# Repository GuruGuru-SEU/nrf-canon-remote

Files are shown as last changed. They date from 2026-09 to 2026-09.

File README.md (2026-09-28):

# nRF52832 Canon remote — mechanical study v0.12

打开 **[在线 3D 预览](https://guruguru-seu.github.io/nrf-canon-remote/preview.html)**，可直接分享这个链接。

也可下载 `output/preview.html` 后用浏览器离线打开，详见 [机械设计说明](output/设计说明.md)。

机身为 **78 × 43 × 17.35 mm**：保留四向圆环、中心两段键和下方三个圆键，删除长条键及底部五个矩形键。中心开关采用 **K2-1831SL-A4SW-01**，其余七个开关采用 TS-1101-C-W。外壳、PCB 外形、固定孔、USB-C 板舌与开孔配套重建；软包电池候选为 EEMB LP402535 / 320 mAh。

USB-C 选用淘宝自购的 **HX TYPE-C 6P QTWT（6Pin 全贴）**，对应立创 C18357553，按当前 PCB 改为底面安装。USB-C、TS-1101-C-W 和 RGB 的预览使用嘉立创下载模型，原始文件与来源见 [器件模型记录](reference/component-models/README.md)。中心两段开关采用界面显示角度 180°，仍按厂家图纸建模；nRF52832 与电池为外形包络。U600 底部声学端口增加 Ø1.2 mm 外壳声孔与 Ø2.2 mm 内侧 relief。

v0.10 修正 USB-C 底面安装的翻转：焊脚朝 PCB，母座主体朝背盖，焊盘同步翻转。恢复参考外壳 USB 端两侧的上盖楔形卡扣和下盖凹槽，托筋避开固定焊耳。中心开关的两个定位孔也随 180° 方向旋转；模型碰撞检查不再豁免 USB / 外壳或开关 / PCB 穿插。预览新增“USB-C 端部配合”和“端部上盖卡扣”。

v0.12 按 2026-09-23 Chrome 最终 PCB 将上方 Ø2.3 孔移至 (14,28)，上下盖螺柱与沉孔同步。最初按 EDA 叠层临时建模为 1.0 mm；2026-09-24 用户确认实际板厚为 1.6 mm，已保持 PCB 上表面不变、将底面和底装 USB-C 下移 0.60 mm，并同步调整托台。USB 模型使用实际焊盘核验原点偏移。

2026-09-28 更新 **[openEMS 天线初步计算报告](https://guruguru-seu.github.io/nrf-canon-remote/rf/antenna-20260923.html)**：使用 9 月 24 日最终 Gerber 的全部两面铜和钻孔、1.6 mm 板厚，以及立创公开 FR-4 参数；提供六组裸板 / 装壳 / 材料敏感性 / 网格细化结果及原始端口数据。此前 PCB 快照计算和匹配候选已被本轮取代。现 PCB 使用印制天线，下面 v0.1 电气草案中的陶瓷天线与部分元件值已不是最终 PCB 版本。RF 结果仍有材料、网格和端口近似，不能直接作为量产匹配 BOM；[复算方法](scripts/rf/README.md)与数据一并提供。

2026-09-28 新增 **[三种候选板材分别计算的报告](https://guruguru-seu.github.io/nrf-canon-remote/rf/materials-20260928.html)**：NP-140F、HY-8101，以及按官方树脂含量表拆分的 NY2140 RC55/RC70。报告同时说明 L 型与 π 型匹配网络，并给出含电感的 C-L-C 候选、材料共用扫描和八组 openEMS 证据。

新增 **[文字原理图 v0.1](output/electrical/原理图-v0.1.md)**：包含 nRF52832 最小系统、9 路按键信号、RGB 驱动、USB／电池供电与充电、4Pin SWD、陶瓷天线、库存 BOM 和布局注释。依据见 [电气参考资料](reference/electrical/README.md)。目前为待转绘和验证的电路草案，不含 EDA 原理图工程、PCB 铜层布局或固件；新增电路器件尚未回填到 3D 模型。

用于分享审阅的 HTML 页面：**[7 页原理图图纸](https://guruguru-seu.github.io/nrf-canon-remote/electrical/schematic-drawing-v0.1.html)**、**[原理图说明](https://guruguru-seu.github.io/nrf-canon-remote/electrical/schematic-v0.1.html)**、**[完整 BOM](https://guruguru-seu.github.io/nrf-canon-remote/electrical/bom-v0.1.html)**。图纸用 Schemdraw 绘制，支持切页、缩放、位号定位和 SVG 下载，每页附连接与 layout 注释；网站首页不增加文档入口。

图纸逐器件标注 `JLC C…` 物料编号，可在嘉立创EDA直接搜索；60 个元件对应 27 种立创物料。RGB 已改为共阳接 VDD、三个 GPIO 经各自限流电阻低有效直驱。未核实或待选型的器件、DNP 和 PCB 自带焊盘分别注明。物料编号与完整 BOM 一致；2026-09-19 新核实的四项供应商链接见 BOM，采购状态仍为待采购。

2026-09-20 按已有开发板用值更新晶振负载：HF、LF 每侧各一颗 12 pF（C210～C213，C45359894），后续电容顺延为 C214～C218；旧／新位号对照见文字原理图 3.2 节。

按键采用 GPIO 直连触点到地，开启内部上拉并由固件去抖；删除 R300～R308、C300～C308 共 18 个元件，半按与全按各自保留独立输入。

3D 预览为机械模型。参考键帽保留形状并平移、修改顶柱；下盖恢复参考工程的梯形截面（43 mm 收至背面 35 mm）；PCB 左上、右上角设 R5 四分之一圆凹口，下盖增加配合定位凸台和托台；采用右上、下左右三点固定。RGB 与导光结构整体下移 5 mm。原始 140 mm 参考模型保留在预览的“原型对照”中。

## 输出

- `output/electrical/原理图-v0.1.md`：可转绘的文字原理图、引脚分配、BOM 和 layout 原则。
- `output/electrical/BOM-v0.1.md`：按电路部分拆分的完整 BOM，包含已有／待采购状态和用途。
- `output/electrical/*.html`：可独立浏览及发布到 Pages 的原理图与 BOM 页面。
- `output/electrical/schematic-assets/*.svg`：7 页矢量电路图，覆盖全部默认装配物料、DNP、测试点和 MCU 48 脚 + EP。
- `output/electrical/schematic-manifest.json`、`schematic-checks.json`：绘图连接数据与检查记录；不是 EDA 网表，也不代表通过 EDA ERC。
- `output/preview.html`：模型及 Three.js 全部内嵌，双击离线打开。支持装配、爆炸、剖切、透明、梯形端面、PCB 板形、角部配合、USB 特写、中心键半按/全按及 STL 下载。
- `output/models/remote_assembly.3mf`：含电子件占位的完整装配。
- `output/models/printable_parts.3mf`：上下盖、五个键帽、导光件，共八件。
- `output/models/*.stl`：各部件，保持装配坐标，单位 mm。
- `output/models/pcb_outline.dxf`、`pcb_outline.svg`：板框、三个安装孔及中心开关的两个定位孔。
- `output/review/`：几何/浏览器检查、截图及尺寸依据。

## 重建与检查

```sh
uv sync --locked
npm ci
uv run python scripts/build_models.py
uv run python scripts/check_exports.py
npm run build
npm run check:preview
```

Python 3.14 与 `.venv` 由 uv 管理，依赖定义于 `pyproject.toml`，精确版本锁定于 `uv.lock`。新增 Python 依赖使用 `uv add 包名`；`requirements.txt` 为兼容 pip 的导出文件，可用 `uv export --no-hashes --no-dev -o requirements.txt` 更新。

更新电气 Markdown 后，运行 `npm run build:docs` 重新导出两份 HTML。构建使用本机 Google Chrome 将 Mermaid 框图渲染为 SVG；最终 HTML 无外部运行时依赖，不需要重新构建机械模型。

图形原理图的连接数据位于 `scripts/electrical_circuit.py`，绘图代码位于 `scripts/draw_schematics.py`。更新电路时同时更新文字原理图、BOM 和连接数据，然后运行：

```sh
npm run build:schematics
npm run check:schematics
```

物料编号及无编号原因维护在 `electrical_circuit.py` 的 `JLC_GROUPS` / `NO_JLC` 中。构建检查每页的器件标注覆盖，校验脚本比对 BOM 编号并确认 SVG 中实际显示了各条标注。

检查覆盖 75 个 BOM 位号/焊盘位置、65 件默认装配物料、41 件电阻/电容/电感的数值、49 个 MCU 引脚、9 路按键直连、3 路 RGB 直驱，以及图中全部 215 个端子的实际连线。浏览器检查包含文字重叠/裁切、移动页面、切页、缩放和位号定位；这些属于文档与绘图一致性检查，不能替代电气 ERC 和样机测试。网页可离线浏览，SVG 下载依赖同目录的 `schematic-assets/`。

布局及开关尺寸统一定义于 `scripts/layout.json`。建模脚本使用 trimesh / manifold，打印件出现非封闭、非连通实体或已检查部件穿透时会终止导出；库模型的检查方式与例外在器件模型记录中列明。浏览器检查使用已安装的 Google Chrome，包含离线加载、视图、两段键运动、STL 导出和移动屏幕排版。

尚未实物验证按键手感、打印公差、螺纹强度、导光混色及 USB 线缆包胶空间；详细尺寸与假设见设计说明。

## GitHub Pages 发布

推送 `main` 分支中的预览、模型或电气 HTML 更新后，GitHub Actions 自动发布 GitHub Pages。网站根目录和 `/preview.html` 均可打开预览，`/models/` 下提供模型下载，`/electrical/` 下提供文档直链。部署过程发布已生成的文件。

修改布局或建模代码后，先执行上面的重建和检查命令，再提交并推送 `scripts/` 与 `output/` 的更新。也可在 Actions 页面手动运行发布工作流。

原始采购订单含个人收货信息，不上传到公开仓库；所用物料见 [公开物料信息](reference/jlc-orders/README.md)。本地虚拟环境、依赖缓存和历史试验文件同样不提交。

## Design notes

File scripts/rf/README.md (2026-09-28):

# Gerber 驱动的 openEMS 计算（2026-09-24）

当前几何来自用户提供的 `Gerber_nRF52832遥控器_2026-09-24.zip`，SHA-256 为 `3fc97f87b7eec812915d751c0682821ee30cdcd28201358806b40dc6174ed5ac`。不再使用前一天封装拼接天线。几何包含全部两面铜、PTH/NPTH；飞针文件只用于识别 L220 焊盘位置。原始 ZIP 保留本地，提取的 JSON 足以复算。没有原始 ZIP 时跳过下方 `extract_gerber.py`，直接使用仓库中的 JSON 运行求解。

独立 uv 环境使用 Python 3.13：

```sh
uv venv --python 3.13 .tools/openems/.venv
uv pip install --python .tools/openems/.venv/bin/python pip setuptools setuptools-scm wheel cython numpy h5py matplotlib shapely scipy gerbonara==1.6.3
```

本机按 [openEMS 官方指南](https://docs.openems.de/en/latest/install/clone-build-install.html) 编译 openEMS 0.37.0 / CSXCAD 0.7.0，安装前缀 `.tools/openems`。系统依赖为 Homebrew 的 cmake、boost、hdf5、cgal、vtk；原生安装不提交 Git。构建扩展时将该 uv 环境加入 PATH，设置 VIRTUAL_ENV，执行 `update_openEMS.sh <安装前缀> --disable-GUI --njobs=8 --python --python-venv-mode=disable`。

```sh
set -o pipefail
mkdir -p tmp
.tools/openems/.venv/bin/python scripts/rf/extract_gerber.py
.tools/openems/.venv/bin/python scripts/rf/simulate.py --name gerber-bare --mesh .2 2>&1 | tee tmp/rf-gerber-bare.log
.tools/openems/.venv/bin/python scripts/rf/simulate.py --name gerber-fine --mesh .15 2>&1 | tee tmp/rf-gerber-fine.log
.tools/openems/.venv/bin/python scripts/rf/simulate.py --name gerber-finer --mesh .1 2>&1 | tee tmp/rf-gerber-finer.log
.tools/openems/.venv/bin/python scripts/rf/simulate.py --name gerber-low-loss --mesh .15 --loss .013 2>&1 | tee tmp/rf-gerber-low-loss.log
.tools/openems/.venv/bin/python scripts/rf/simulate.py --name gerber-dk43 --mesh .15 --eps 4.3 2>&1 | tee tmp/rf-gerber-dk43.log
.tools/openems/.venv/bin/python scripts/rf/simulate.py --name gerber-housed --mesh .15 --shell-eps 2.8 2>&1 | tee tmp/rf-gerber-housed.log
.tools/openems/.venv/bin/python scripts/rf/analyze_gerber.py
node scripts/rf/build_report.mjs
```

三份板材的独立计算与汇总：

```sh
.tools/openems/.venv/bin/python scripts/rf/run_materials.py --threads 4
.tools/openems/.venv/bin/python scripts/rf/analyze_materials.py
python3 scripts/rf/build_material_report.py
node scripts/rf/build_material_report.mjs
```

`analyze_materials.py` 会校验八组实际求解、扫描 L/π 理想匹配网络，并生成
`output/rf/materials-matching.json`、对比图和求解证据 ZIP。NY2140 按制造商
R/C 55% 与 70% 两个官方表格工况分别计算；三份输入 PDF 和参数清单在
`reference/rf/materials/` 与 `reference/rf/materials-20260928.json`。

运行名唯一对应几何和参数，不要对仍在运行的目录再次执行。`--post` 只后处理已有时域数据，必须使用相同参数。

默认板厚 1.6 mm，Dk=4.5，Df=0.02。材料来源及频率限制见 `reference/rf/materials-20260924.json`。Dk=4.5 是立创双层板公开典型值；Df=0.02 是其 1 MHz 通用值，不能声称为此订单 2.4 GHz 实测值。低损耗对照 Df=0.013 来自建滔 KB-6160 厚芯板 2 GHz 参数，未断言订单使用此料号。

50 Ω 集总端口位于 **L220 天线侧焊盘**，跨板厚连接对面地铜。电路元件不装，不包含射频芯片阻抗。C216/L220/C217 数值未嵌入 EM 模型。匹配综合同时扫描并联支路在负载端 / 输入端的两种理想 L 网络，仅适用于这个端口。不能直接套用到现板位号。

模型保留 Gerber 中细小铜间隙及独立焊盘的嵌套关系，但 FDTD 网格可能遗漏小图元，日志会记录警告。过孔按孔半径 + 25 µm 的实心导体近似，铜采用 PEC 片，阻焊开窗已解析但介质本身未纳入。省略元件负载、铜损、USB 金属、螺钉、人体；装壳组仅假设上下盖 εr=2.8、tanδ=0.01，并加入机械布局对应的浮置电池导体包络。

`gerber-solver-evidence.zip` 保存本轮所有求解日志、端口时域数据和参数。历史 `*-16` 及无后缀输出保留对照；它们不是最新 Gerber 结果。旧快照提取脚本 / 旧匹配脚本仅供历史复现，默认主流程以上述命令为准。

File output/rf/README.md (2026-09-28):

# 最终 Gerber · 1.6 mm PCB 天线计算

**2026-09-28 整理完成。** 已按用户提供的 `Gerber_nRF52832遥控器_2026-09-24.zip` 重建电磁几何，完成六组 openEMS 仿真。本文替代此前基于 PCB 快照的报告；旧的 `42.1 + j47.4 Ω` 裸板结果及其匹配候选不再作为当前版本的依据。

> 初步结论：当前模型的天线馈点偏感性，装壳和电池影响明显。计算可以提供调试起点，但尚不足以确定最终匹配 BOM。以下均为仿真结果，非样机实测。

## 简报

| 条件 | 2.441 GHz 输入阻抗 | BLE 频段最差未匹配 S11 |
|---|---:|---:|
| 裸板，最细 0.10 mm 射频 XY 网格 | **11.10 + j45.44 Ω** | **−1.74 dB** |
| 裸板，0.15 mm 网格（装壳组对照） | 11.72 + j48.07 Ω | −1.75 dB |
| 装壳 + 浮置电池包络，0.15 mm 网格 | **12.05 + j118.82 Ω** | **−0.56 dB** |

频段为 **2.402–2.480 GHz**，阻抗参考面位于 **L220 天线侧焊盘 `$1N324`**。正虚部表示感性。这里测的是该焊盘看向馈线与天线的输入阻抗，不是 nRF52832 ANT 引脚阻抗，也不是完整装配电路的输入阻抗。

有限取值的理想两元件匹配扫描得到：裸板可用**输入侧并联 1.8 pF + 串联 3.0 pF**作为计算候选，频段最差 S11 约 **−8.58 dB**；装壳假设下另行扫描的候选为**输入侧并联 1.5 pF + 串联 0.7 pF**，约 **−6.55 dB**。这两组在本次扫描中均未覆盖全频段 −10 dB 目标，不能据此宣称天线已经调好，也不代表所有网络都无法达到目标。

## 立创 FR-4 参数依据

- [立创官方 PCB 能力表](https://jlcpcb.com/capabilities/pcb-capabilities)给出的双层 FR-4 介电常数为 **Dk = 4.5**，此项没有标明频率。本轮采用它作为名义基准。
- [立创官方 FR-4 页面](https://jlcpcb.com/pcb-fabrication/fr4-pcb)给出典型 **Df ≈ 0.02（1 MHz）**。它不是本订单在 2.4 GHz 的已知实测值；本轮仅用作基准假设。
- [建滔 KB-6160 官方材料表](https://www.kblaminates.com/upload/ueditor/20220525/KB-6160-0831.pdf)中，59 mil / 7628×8 一行在 2 GHz 给出 Dk = 4.5、Df = 0.013，Dk 公差 ±0.2。本轮增加 **Df = 0.013** 和 **Dk = 4.3** 两组独立敏感性计算；这不表示已确认订单使用 KB-6160，也不是该订单的公差承诺。

板厚采用用户确认的 **1.6 mm**。Gerber 本身不包含板材牌号和介电参数。源网页查阅日期为 2026-09-24；[参数记录与来源校验值](https://github.com/GuruGuru-SEU/nrf-canon-remote/blob/main/reference/rf/materials-20260924.json)可供追溯。

## 实际建模内容

本次直接解析最终制造文件中的两面全部铜、板框、101 个 PTH 和 6 个 NPTH。`Drill_PTH_Through_Via.DRL` 的过孔已包含在总 PTH 文件内，没有重复建模。飞针数据用于识别 L220 馈点；Gerber 铜几何已核对天线馈点、IFA 短路端以及 L220 两焊盘的分离关系。

天线直接来自最终底层 Gerber，没有用旧封装拼接。天线顶部区域与前一版快照基本一致；但本次纳入全部网络铜、完整钻孔和新的材料参数，因此两版模型不等价，不能把全部阻抗差异归因于 Dk 的变化。

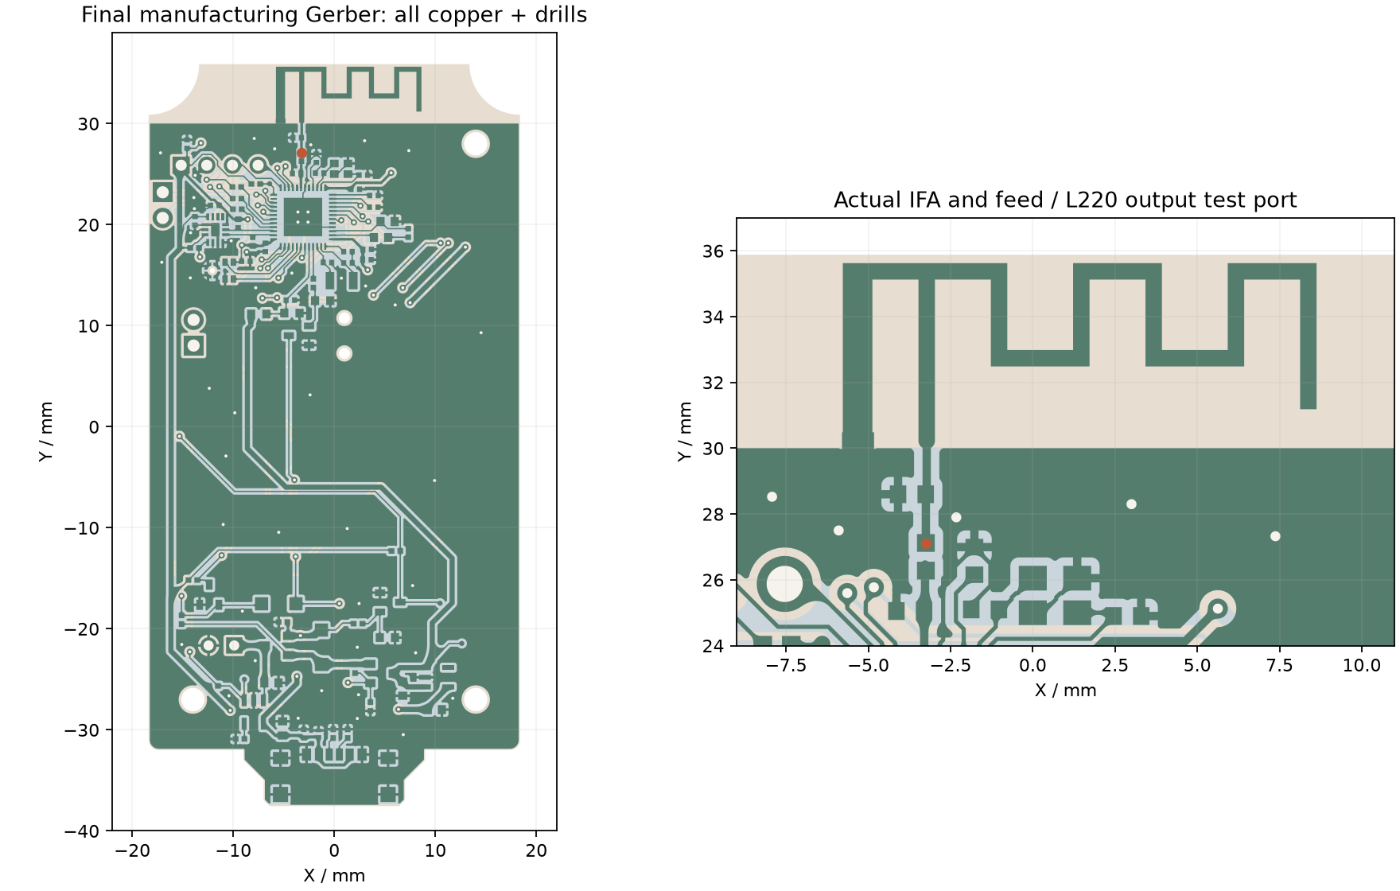
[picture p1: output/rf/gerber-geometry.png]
最终 Gerber 铜层、钻孔及 L220 馈点


图中底层铜为深绿、顶层铜为灰蓝，橙点为仿真端口。左图全板，右图放大天线区域。

- 铜采用 PEC 薄片；板厚换算为 **1.545 mm 铜面间距**，扣除名义铜厚及阻焊余量。这是近似叠层，不是板厂确认的实际叠层。
- PTH 采用孔半径 + 25 µm 的实心导体近似，不是空心孔壁模型。阻焊开窗已提取供核查，阻焊介质未纳入求解。
- 50 Ω 集总端口沿板厚连接底面 RF 焊盘与正对的顶面地铜，未做实际同轴探针和测试夹具去嵌。
- 器件不装配；C216、L220、C217 数值和芯片阻抗未嵌入模型。其他网络保留铜，但没有器件负载；这与完整 PCBA 有区别。
- 装壳组使用 v0.12 上下盖 STL，假设壳体 εr = 2.8、tanδ = 0.01，并加入机械布局对应的浮置导体电池包络。电池引线、USB 金属壳、按键、螺钉和人体均未包含。
- FR-4 损耗通过 2.45 GHz 处的等效电导率实现，在该频率对应所设 Df；没有模拟完整的材料频散。

## 六组结果与数值检查

| 计算组 | 射频 XY 网格 | Dk / Df | 2.441 GHz 阻抗 | 频段最差 S11 |
|---|---:|---:|---:|---:|
| 裸板基准 `gerber-bare` | 0.20 mm | 4.5 / 0.020 | 11.14 + j53.32 Ω | −1.52 dB |
| 裸板细化 `gerber-fine` | 0.15 mm | 4.5 / 0.020 | 11.72 + j48.07 Ω | −1.75 dB |
| 裸板再细化 `gerber-finer` | 0.10 mm | 4.5 / 0.020 | 11.10 + j45.44 Ω | −1.74 dB |
| 较低损耗 `gerber-low-loss` | 0.15 mm | 4.5 / 0.013 | 10.73 + j48.02 Ω | −1.61 dB |
| 较低介电常数 `gerber-dk43` | 0.15 mm | 4.3 / 0.020 | 12.05 + j41.64 Ω | −2.00 dB |
| 壳体与电池 `gerber-housed` | 0.15 mm | 4.5 / 0.020 | 12.05 + j118.82 Ω | −0.56 dB |

六组均达到 **−40 dB 时域能量停止阈值**。已经检查端口数据有限、实部为正，并核对阻抗换算 S11 与导出的 Touchstone 一致。这是基本数值检查，不等于与实物一致。

裸板射频区 XY 网格从 0.20 → 0.15 mm 时，中心频率阻抗变化 **10.68%**；0.15 → 0.10 mm 时仍变化 **5.77%**，频段内最大阻抗差 **3.28 Ω**。板厚方向保持 5 个单元，外围网格较粗，装壳组未继续细化。最细组还有 19 条未被网格使用的图元警告，涉及小铜片、空隙和部分孔柱。**因此不能声称严格网格收敛，也不应把上述小数位理解为实际精度。**

## 匹配候选怎么理解

下图仅表示在该参考面前接入理想网络后的电路关系，不是现有 PCB 的元件位号替换图：

```text
理想 50 Ω 输入 ──●──── Cs ──── 原始 Gerber 负载
                 │               ↑ L220 天线侧参考面
                 Cp
                 │
                GND
```

| 针对条件 | 输入侧并联 Cp | 串联 Cs | 匹配后频段最差 S11 |
|---|---:|---:|---:|
| 裸板，0.10 mm 网格 | 1.8 pF | 3.0 pF | −8.58 dB |
| 装壳假设，0.15 mm 网格 | 1.5 pF | 0.7 pF | −6.55 dB |

将同一组裸板候选用于 0.15 mm 裸板时，最差 S11 为 −7.34 dB；用于装壳组仅为 **−0.47 dB**。这说明当前误差和装配环境足以改变匹配值。0.15 mm 与 0.10 mm 两组裸板各自扫描得到的串联电容也分别为 2.7 pF 和 3.0 pF。

扫描同时考虑输入侧、负载侧并联的两种 L 网络，候选包含电容 0.2–10 pF、电感 0.5–22 nH 中的离散值及开路 / 短路；目标是降低 BLE 频段最差 S11。元件为理想集中参数，未计入 Q、ESR、SRF、焊盘和走线寄生。上述数值不能直接替换现有 L220 / C216 / C217，也不取代芯片端的 Nordic 参考网络。

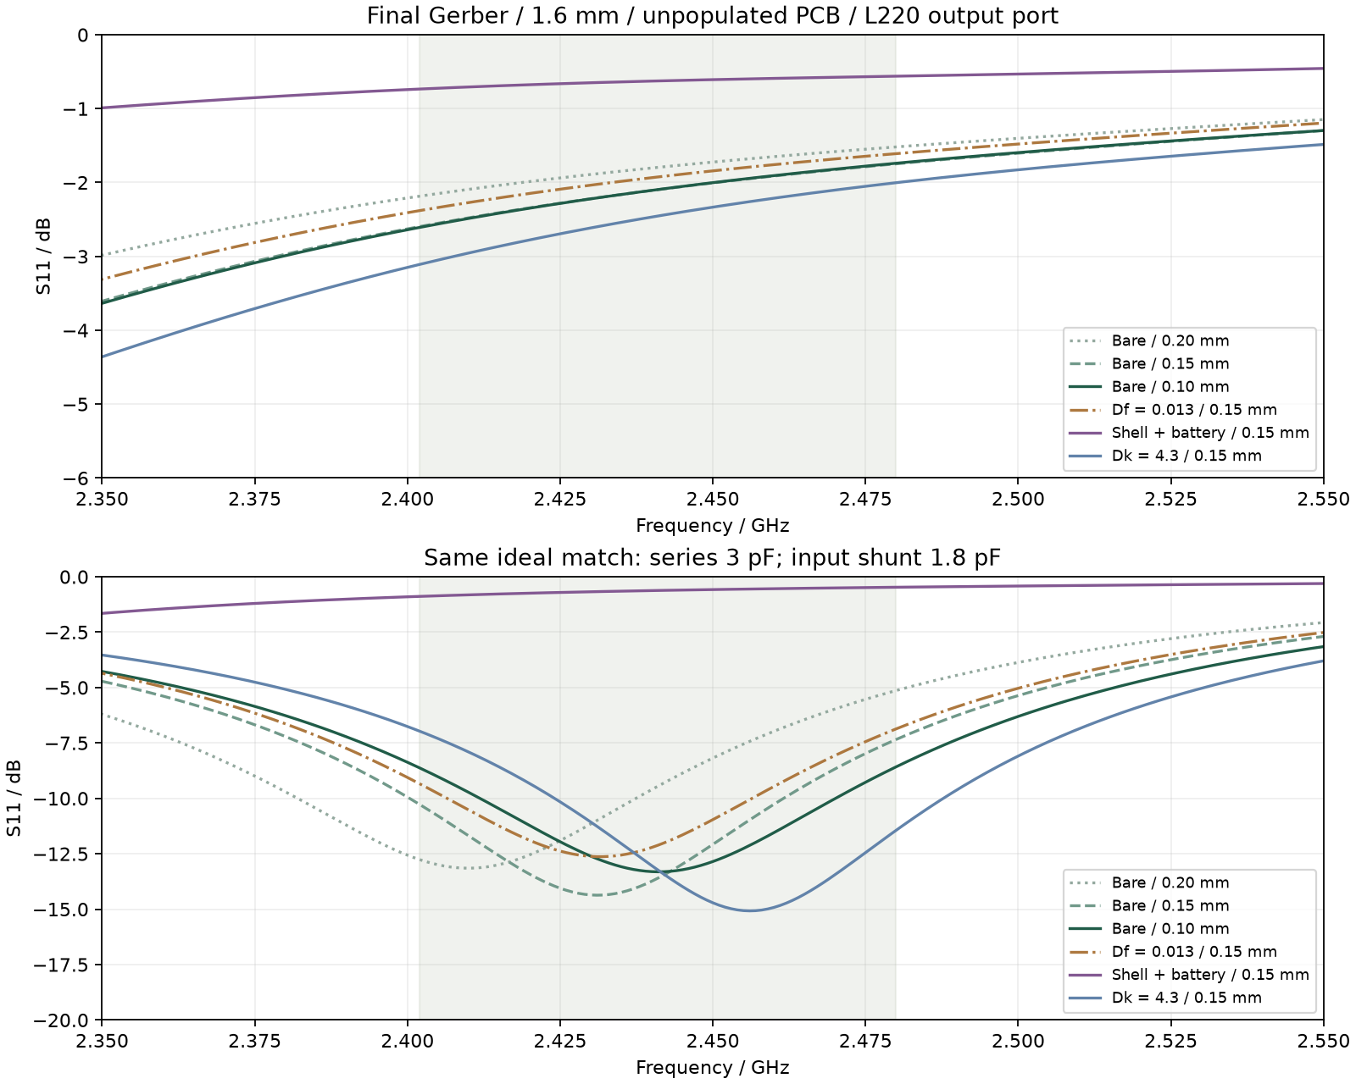
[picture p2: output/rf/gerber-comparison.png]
未匹配与同一裸板候选作用下的 S11 对比


上图为各条件原始 S11，下图统一使用裸板候选 Cp = 1.8 pF、Cs = 3.0 pF，绿色阴影表示 BLE 频段。下图没有对各曲线单独重新优化。

**建议下一步：** 保留天线端调试焊盘，先确认实际板材及叠层，再用最终电池与外壳装配样机，在一致的参考面通过 VNA 测量后选定元件。当前结果支持“需要调谐且装壳影响大”这一判断；本次没有计算辐射效率或遥控距离。

## 下载与复算

- [0.10 mm 裸板 S1P](gerber-finer.s1p) · [CSV](gerber-finer.csv) · [参数](gerber-finer.json)
- [0.15 mm 裸板 S1P](gerber-fine.s1p) · [CSV](gerber-fine.csv) · [参数](gerber-fine.json)
- [0.20 mm 裸板 S1P](gerber-bare.s1p) · [CSV](gerber-bare.csv) · [参数](gerber-bare.json)
- [装壳与电池 S1P](gerber-housed.s1p) · [CSV](gerber-housed.csv) · [参数](gerber-housed.json)
- [Df = 0.013 对照 S1P](gerber-low-loss.s1p) · [CSV](gerber-low-loss.csv) · [参数](gerber-low-loss.json)
- [Dk = 4.3 对照 S1P](gerber-dk43.s1p) · [CSV](gerber-dk43.csv) · [参数](gerber-dk43.json)
- [匹配扫描与数值检查](gerber-matching.json) · [Gerber 几何核查](gerber-audit.json)
- [六组求解日志、端口时域数据与参数 ZIP](gerber-solver-evidence.zip)
- [提取的制造几何](https://github.com/GuruGuru-SEU/nrf-canon-remote/blob/main/reference/rf/gerber-20260924.json) · [复算步骤与脚本](https://github.com/GuruGuru-SEU/nrf-canon-remote/tree/main/scripts/rf)
- [机械 3D 预览](../preview.html?rev=0.12) · [装配 3MF](../models/remote_assembly.3mf)

原始 ZIP 的 SHA-256：`3fc97f87b7eec812915d751c0682821ee30cdcd28201358806b40dc6174ed5ac`。源文件导出时间为 2026-09-24 14:07:48。本轮没有修改用户 PCB Layout。旧计算文件保留供历史比较，均不代表本次最终 Gerber 结果。

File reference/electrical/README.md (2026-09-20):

# 电气设计参考资料

核对日期：2026-09-17。本目录收录首次文字原理图使用的厂商资料，版权归各原作者。工程设计见 [原理图 v0.1](../../output/electrical/原理图-v0.1.md)。采购来源和设计选型不同：目录中有资料，不代表该器件已经采购。

## Nordic

| 资料 | 原始来源 | 本地文件／用途 |
| --- | --- | --- |
| nRF52832 QFAx Reference Layout v1.1 | [Nordic 官方 ZIP](https://nsscprodmedia.blob.core.windows.net/prod/software-and-other-downloads/reference-layouts/nrf52832qfaxreflayoutv11.zip) | [QFAA DC/DC 原理图](nrf52832_qfaa_dcdc_schematic.pdf)、[QFAA DC/DC PCB](nrf52832_qfaa_dcdc_pcb.pdf)，从官方压缩包提取，未改动 |
| Product Specification：引脚 | [Pin assignments](https://docs.nordicsemi.com/r/bundle/ps_nrf52832/page/pin.html) | QFN48 的脚号、VDD、VSS、DEC 与 GPIO |
| Product Specification：参考电路 | [Reference circuitry](https://docs.nordicsemi.com/r/bundle/ps_nrf52832/page/ref_circuitry.html) | 3.9 nH / 0.8 pF RF 网络、DC/DC 和去耦 BOM |
| Product Specification：时钟 | [CLOCK](https://docs.nordicsemi.com/r/bundle/ps_nrf52832/page/clock.html) | 晶体负载、引脚电容、ESR、精度要求 |
| Product Specification：ADC | [SAADC](https://docs.nordicsemi.com/r/bundle/ps_nrf52832/page/saadc.html) | 电池分压的采集时间与输入范围 |
| Product Specification：GPIO | [GPIO](https://docs.nordicsemi.com/r/bundle/ps_nrf52832/page/gpio.html) | RGB 直驱采用 H0S1；驱动电流、低电平压降与初始化配置 |
| Errata 138 | [Rev.3 anomaly 138](https://docs.nordicsemi.com/r/bundle/errata_nrf52832_rev3/page/err/nrf52832/rev3/latest/anomaly_832_138.html) | P0.25/P0.26 的参考电容处理 |
| PCB 指南 | [nRF52832 Specific PCB Guidelines](https://devzone.nordicsemi.com/guides/hardware-design-test-and-measuring/b/nrf5x/posts/nrf52832-specific-pcb-guidelines) | 补充解释 DEC2 的封装差异、C13/C14 和局部布局；该页面标为旧指南，结合当前规格及官方参考文件使用 |

## 库存器件资料

| 物料 | 文件 | 来源／核对内容 |
| --- | --- | --- |
| C52212029 / NH-B1515RGBA-GF | [PDF](NH-B1515RGBA-GF.pdf) | [国星厂商 PDF，立创托管](https://atta.szlcsc.com/upload/public/pdf/source/20251030/EECF4F56E4F8547E9265236F0C1AEE5B.pdf)；第 6 页引脚，2 共阳、1 红、3 蓝、4 绿 |
| C2925419 / KH-2012-HM1 | [PDF](KH-2012-HM1.pdf) | [金航标官网 PDF](https://www.kinghelm.net/upload/file/20240619/KH-2012-HM1.pdf)；第 2 页焊盘与净空，1 INPUT、2 NC；第 3 页示例板和匹配 |
| C49208527 / MSTP4054-42 | [PDF](MSTP4054-42.pdf) | [美森科厂商 PDF，立创托管](https://atta.szlcsc.com/upload/public/pdf/source/20250701/DF15CD7DF13D43087D35725B366D9DAB.pdf)；引脚、电流公式、充电终止条件 |
| C82942 / ME6211C33M5G-N | [PDF](ME6211.pdf) | [微盟 ME6211 系列 PDF，立创托管](https://atta.szlcsc.com/upload/public/pdf/source/20170918/C82942_1505727073070976520.pdf)；SOT23-5 的 C 系列引脚及 C33 电气参数；首页与 C33 表静态电流存在差异，按较高值预算 |
| C2891732 / SI2302 | [PDF](SI2302.pdf) | [永裕泰厂商 PDF，立创托管](https://atta.szlcsc.com/upload/public/pdf/source/20260225/4C26798752F14A6C8689DB8E1FD76F36.pdf)；N-MOS，1G/2S/3D，低压栅极驱动规格 |
| C54427949 / YE32MDBCD2X | [系列 PDF](YE32MDBCD2X.pdf) | [雅晶鑫系列 PDF，立创托管](https://atta.szlcsc.com/upload/public/pdf/source/20260323/688CCC4499BA77041AC465C19328DD85.pdf)；1/3 晶体、2/4 GND。完整料号的 32 MHz / 10 pF 见库存记录与[对应商品](https://item.szlcsc.com/57752896.html)，通用 PDF 未单独列出该订购后缀 |
| C18209174 / KFC3276812520T | [PDF](KFC3276812520T.pdf) | [凯越翔厂商 PDF，立创托管](https://datasheet.lcsc.com/datasheet/pdf/f310e2e4c21d4f7a5e8427f5db47ddd3.pdf?productCode=C18209174)；CL=12.5 pF、32.768 kHz、ESR 最大 70 kΩ |
| C411950 / SCL1608S100KSP，**不选用** | 系列数据来源 | [顺翔诺 SCL 系列 PDF，立创托管](https://datasheet.lcsc.com/lcsc/2304140030_Sunltech-Tech-SCL1608Q3R3KSP_C411948.pdf)；链接所属 SKU 是同系列其他感值，需读表内 **SCL1608S100KSP** 行；额定电流 3 mA，不能当作 Nordic 参考电路要求的 ≥50 mA 电感 |

USB-C 与普通轻触开关的库资料继续使用 [component-models](../component-models/README.md)。中心开关使用 [K2-1831SL-A4SW-01 厂商图纸](../../output/review/k2-1831sl-datasheet.pdf)，以图中的 a/b/c 触点标记核对封装。

## 本版新增选件依据

- [AO3401A，AOS 厂商规格](https://www.aosmd.com/pdfs/datasheet/AO3401A.pdf)（[本地 PDF](AO3401A.pdf)）：P-MOS 电池通路，不能以库存 SI2302 N-MOS 代替。
- [BAT54H，Nexperia 厂商规格](https://assets.nexperia.com/documents/data-sheet/BAT54H.pdf)：SOD123F 肖特基，用于 USB→VSYS；只通过系统电流。
- [MLZ1608M100WT000，TDK 厂商页面](https://product.tdk.com/en/search/inductor/inductor/smd/info?part_no=MLZ1608M100WT000)：10 µH、0603、电感变化额定电流 90 mA。

RF 的 3.9 nH 和 0.8 pF 按 Nordic QFN48 参考 BOM 新增采购，完整厂商料号尚未锁定；天线匹配预留元件待实板调试。没有把库存近似值标成已验证替代件。

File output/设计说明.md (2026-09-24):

# 遥控器机械改型 v0.12

本版机身 **78 × 43 × 17.35 mm**（不含按键突出），相比原始 140 mm 缩短 62 mm。保留四向圆环、中心键、下方三个圆键，共五个键帽、八个开关；三个长条键和底部五个矩形键全部删除。中心开关改为 **K2-1831SL-A4SW-01**，其余七个为 **TS-1101-C-W**。本版按 Chrome 中当前 PCB 的界面显示角度，将中心两段开关设为 **180°**。

打开 [preview.html](preview.html) 可离线预览。提供“中心两段键”特写、“中心剖切”及“松开 / 半按 / 全按”控制。动作表示几何行程；不表示已实现对焦、快门或 BR-E1 协议。

## 模型来源与边界

原始文件为 `reference/enclosure/shell_top.3mf`、`shell_bottom.3mf`、`buttons_blank.3mf`，板框参考 `reference/pcb/GerberFiles/profile.gbr`。

本版上下壳按参考的宽度、厚度、圆角和正面倒角风格重新建立，安装结构采用右上、下左右三组配套螺柱。不是直接沿用原壳全部内结构。圆环、中心、三个圆键保留原始键帽形状，只做刚性平移并增加相应顶柱；没有将圆形沿单轴压缩。原型对照展示未缩放的原始 140 mm 外壳、全部原始键帽及 Gerber 板框。

PCB 仅做机械外形、孔及 USB 焊盘配合展示，不包含原理图、铜层布线或完整封装设计。USB-C、七个 TS-1101-C-W 与 RGB 的预览使用嘉立创原始下载网格，来源、UUID、SHA-256、坐标转换及限制见 [器件模型记录](../reference/component-models/README.md)。当前 HX TYPE-C 6P QTWT 按 EasyEDA 中 J100 的底面安装状态翻到 PCB 下方，库模型使用底面镜像并保留其开口朝机身尾端的 XY 基准；焊脚面与十个 PCB 焊盘逐一检查。顶部外壳不切 USB 开口；下盖保留端口贯穿孔、11 × 5.1 mm 外侧浅让位及 12.4 mm 耳位让位。USB 端两侧恢复参考外壳的上盖楔形卡扣和下盖凹槽，扣槽名义间隙 0.15 mm、与 PCB 边缘间隙 0.25 mm。U600 为底部声孔麦克风，下盖新增 Ø1.2 mm 声孔与 Ø2.2 mm 内侧 relief。中心 K2-1831SL-A4SW-01 仍按厂家图纸建模；主控和电池为包络。STL/3MF 为网格实体，没有原生 CAD 特征树或 STEP 曲面。

## 统一坐标与布局

从正面看，X 向右，Y 向遥控器顶部，Z 向观察者。外壳正面 Z=0；全部尺寸单位 mm。

| 项目 | 当前尺寸 / 坐标 |
| --- | --- |
| 壳体 | X=±21.5；Y=±39；Z=-17.35 至 0 |
| 面板 / 侧壁 | 厚 1.20 / 1.70 |
| 分壳缝 | 上壁到 Z=-5.10，下壁到 -5.30，名义轴向间隙 0.20 |
| 圆环与中心键 | 中心 (0, 9) |
| 圆环四开关 | (0,18.69)、(-9.69,9)、(9.69,9)、(0,-0.69) |
| 三个圆键及开关 | (-11.43,-14)、(0,-14)、(11.43,-14) |
| LED / 导光孔 | (-11.43,29) |
| PCB | 总长 73.4287、宽 36.7574、厚 1.60；Y=-37.55 至 +35.8787 |
| PCB 高度 | 下表面 -9.05；上表面 -7.45 |
| 三个固定轴 | 右上 (14,28)；下左右 (-14,-27)、(14,-27) |
| 固定孔 | PCB Ø2.30；下壳通孔 Ø2.20 / 沉孔 Ø4.20；上壳导孔 Ø1.70 |
| 按键孔侧隙 | 由真实键帽截面向外偏移 0.20 |

固定方式按 M2 级螺钉尺寸预留，尚未选定螺钉、验证塑料螺纹或拉拔强度。下盖托起 PCB、上盖螺柱抵住 PCB 上表面；三轴完全对应。

## 顶角四分之一圆凹口与下盖配合

PCB 主体两侧为直边。左上、右上角以 (±18.3787,35.8787) 为圆心，各切除一个 **R5 的四分之一圆**，属于凹形让位。底角保留 R1。板框宽度 36.7574、板顶 Y=35.8787，包含 USB 板舌后的总长为 73.4287 mm。

参考工程下盖有与 PCB 圆弧让位配合的圆形凸台。本版将这种配合方式移至两个上角，重新设计定位台并与下盖侧壁、底板合为一体，参考截面见 [原工程板框与下盖](review/reference-pcb-retention.png)。

| 顶角配合 | 当前参数 |
| --- | --- |
| 凹口圆心 | (-18.3787,35.8787)、(18.3787,35.8787) |
| PCB 凹口 | R5.00，圆弧角度 90° |
| 下盖定位凸台 | R4.75，与凹口同心；名义径向间隙 0.25 |
| 导入斜面 | 从 PCB 顶面 Z=-7.45 到 -7.05，高 0.40、径向缩小 0.40 |
| 下方托台 | R5.60，伸到 PCB 下方；顶面 Z=-9.20，距 PCB 下表面 0.15 |
| 上下盖配合 | 定位凸台最高 -7.05，低于上盖配合唇底部 -6.50 |
| 螺丝固定 | 右上 (14,28)、下左右 (±14,-27)，PCB 孔 Ø2.30 |

凸台外侧裁到原有壳体包络内，保持梯形外形。角部凸台负责定位、托台预留支撑间隙；螺丝固定仍由三组贯穿 PCB 的安装柱承担。0.25 / 0.15 mm 是建模名义间隙，实际打印和 PCB 外形加工公差需样件核对。

RGB、上盖透光孔、导光柱及遮光筒保持 v0.7 的坐标 **(-11.43,29)**（相较 v0.6 下移 5 mm）。LED 位于有效板面内；导光件与两侧定位台、按键均已做干涉检查。

下盖继续采用参考工程的梯形截面：外侧从 Z=-11.35 开始斜收，到 Z=-17.35 时左右各内收 4.00，宽度由 43 变为 35 mm。内壁从 Z=-11.7367、X=±19.8 收到内底面 Z=-16.15、X=±16.8578，底板厚 1.20 mm。两下方沉孔到背面侧边的名义边距为 1.40 mm。

预览中的“PCB 板形”展示两个凹形顶角；“角部配合”展示 PCB、下盖与 LED。该视图下取消“PCB 与 USB 板舌”图层，可查看下盖定位凸台和托台。

## 中心两段式开关

依据韩荣官网提供的 **K2-1831SL-A4SW-□□** 图纸（尾号为序列号）建立 A4SW-01 机械模型。图纸保存在 [k2-1831sl-datasheet.pdf](review/k2-1831sl-datasheet.pdf)，可查看 [尺寸图](review/k2-1831sl-drawing.png)。未用相近的 SF 系列或 A4SA 型替代尺寸。

| 项目 | 厂家尺寸 / 当前适配 |
| --- | --- |
| 主体 | 6.20 × 6.50 × 2.00 |
| 最高点 | 距 PCB 上表面 3.80（主体 2.00 + 操作柱 1.80） |
| 操作柱 | Ø2.50 |
| 四端子 | 外侧总跨度 8.40；两排间距 4.50；端子宽 0.70 |
| 定位柱 | 两根 Ø1.00，伸入板内 0.80；相对开关中心 (-1,±1.75) |
| PCB 定位孔 | 两个 Ø1.10，绝对坐标 (1,7.25)、(1,10.75) |
| 第一段 / 第二段累计行程 | 0.30 / 0.55；第二段不是额外再下压 0.55 |
| 中心键顶柱 | Ø2.10；底端 Z=-3.50，比普通键顶柱缩短 1.30 |
| 静态间隙 | 开关顶面 -3.65 至键帽顶柱底端 -3.50：0.15 |
| 半按 / 全按键帽总位移 | 0.45 / 0.70，包含 0.15 空程 |

中心键源外观保持不变。开关壳体中预留操作柱运动腔，仅用于几何示意，不复刻内部弹片。预览中键帽与开关操作柱分别按总位移和实际开关行程移动。几何检查覆盖中心键 0–0.70 mm 内 15 个位置，检查上盖、圆环、PCB、开关壳体及运动操作柱的接触关系。

普通七个开关使用 C318938 原始库模型，整体包络约 8.007 × 3.70 × 2.498（含焊脚）；名义总高 2.50。普通键顶柱底面 -4.80，与下载模型最高点的间隙约 0.152。普通键按 0.15 空程 + 0.25 行程进行轴向下压检查。圆环实际倾斜、材料弹性、回弹和两段手感仍需打印试装；0.15 是名义值，不是已完成公差叠加后的保证值。

## USB-C、供电与导光

| 项目 | 当前尺寸 / 处理 |
| --- | --- |
| USB-C | 淘宝自购 HX TYPE-C 6P QTWT；对应立创 C18357553，6Pin 全贴 |
| 母座主体 | 图纸主体 8.94 × 6.80 × 3.16；库模型焊耳宽 11.44，图纸 11.80；库网格总高（含焊脚）3.26 |
| USB 前 / 后端 | Y=-39.20 / -32.40；母座口比壳体尾端名义平面伸出 0.20 |
| 端口中心 | X=0，Z=-10.73（距 PCB 下表面 1.68，底面安装） |
| 板舌 | 相对主板底边 Y=-32 向下延伸 5.55，到 -37.55；中央直段宽 14 |
| 贯穿开孔 | 9.60 × 3.90；宽向单侧 0.33、高向约 0.37 名义间隙（下盖） |
| 内侧板舌让位 | 焊耳让位宽 12.40；外侧浅让位 11.00 × 5.10；底面 USB 与下盖配合 |
| USB 库焊盘 | 六个端子 + 四个固定脚，全部为 SMT；距板边最小约 0.407 mm |
| 外侧浅让位 | 11.0 × 5.1，用于入口倒让；下盖两侧另有参考楔形扣槽 |
| 板舌托筋 | 两根宽 1.50，顶面 -9.20，距 PCB 下表面 0.15 |
| 电池候选 | EEMB LP402535，320 mAh；厂商外形 25.5 × 36 × 4.3 |
| 电池位置 | 中心 (0,0)，底面 -15.40、顶面 -11.10，位于 PCB 背面 |
| 电池空间 | 27 × 40 × 5.2 名义分配；四周限位不预压软包 |
| 主控 | nRF52832，6 × 6 × 0.85 QFN48 包络；PCB 背面中心 (0,21) |
| RGB | 订单 C52212029 / NH-B1515RGBA-GF；嘉立创源网格 1.6 × 1.5 × 1.02 |
| 导光孔 / 导光柱 | Ø3.50 / Ø3.20；可见顶面 Z=+0.15 |
| 导光肩 / 遮光筒 | 肩 Ø4.50；上壳一体遮光筒外径 Ø6.30 |
| 导光件底部 | Z=-5.98；距库模型 LED 顶面 0.45 |
| 麦克风声孔 | U600 中心 (-11.25,15.45)；下盖 Ø1.20，内侧 Ø2.20 relief |

电池是另购候选，需按实际保护板、引线和封边版本核对，未宣称复用原 BOM 的 1100 mAh 电池。RGB 按库模型总高 1.02 调整导光柱，较上一版缩短 0.32；高度及焊接偏差仍需实物核对。导光柱需独立采用透明材料，从内侧装入后在肩部固定。

USB 直接采用该物料关联的嘉立创 3D 模型，六个端子焊脚与四个外壳固定脚均为 SMT，不增加通孔。显示其库封装焊盘用于板边支撑核对，未设计铜层和电气网络。库网格焊耳总宽与 HX 图纸相差 0.36，已额外检查 11.80 mm 的较宽包络，未缩放预览网格。入口为充电用途规划；正式封装、插头包胶、焊接/打印偏差及受力仍需验证。

## 物料来源

| 用途 | 物料来源 | 本版数量 |
| --- | --- | --- |
| 中心开关 | `reference/jlc-orders/another-one.txt`：K2-1831SL-A4SW-01 | 1 |
| 其他开关 | SO26050844135，第 17 项；C318938 / TS-1101-C-W，订单 10 个 | 7 |
| USB-C | 淘宝单独购买 HX TYPE-C 6P QTWT；对应 C18357553，不在立创订单中 | 1 |
| RGB | SO2607130348，第 6 项；C52212029 | 1 |
| 主控 | 所给订单中未找到 nRF52832，按指定型号占位 | 1 |
| 电池 | EEMB LP402535 候选，另购 | 1 |

订单数量不代表当前实际库存。充电芯片、稳压器、天线、其他阻容尚未做电气适配；新增麦克风条目不属于本轮机械改型范围。

## 导出与检查结果

- [完整装配 3MF](models/remote_assembly.3mf)：含电子器件占位，不应整件打印。
- [打印件 3MF](models/printable_parts.3mf)：上盖、下盖、五个键帽、导光件，共八件。
- [中心两段键 STL](models/key_center.stl)、[上盖](models/shell_top.stl)、[下盖](models/shell_bottom.stl)、[PCB](models/pcb.stl)。
- [PCB DXF](models/pcb_outline.dxf) / [SVG](models/pcb_outline.svg)：一个外轮廓、三个固定孔、两个开关定位孔。

STL/3MF 保留统一装配坐标，单位 mm；切片前分别选择方向并落到热床。`models` 已移除不再使用的矩形键与长条键导出，避免误用旧版。

[几何报告](review/geometry-checks.json) 检查 29 个部件的碰撞实体，对 59 组包络重叠候选做布尔求交，目前无外部装配穿透。USB/普通开关先将各自库模型的内部实体合并，RGB 的非封闭库网格以保守外包络检查。USB 焊盘和电池胶带属于表面展示，不参与装配碰撞；USB 十个焊盘另逐一做了金属接触检查。另检查 11.80 mm 焊耳包络、两个 90° 凹口及同心凸台间隙、孔位、顶柱连接、中心键 15 个按压位置，以及参考梯形宽度。所有打印件均为封闭、正体积、单体连通网格。

[导出检查](review/export-checks.json) 重新读取全部 11 个 STL 和两份 3MF，确认实体有效、包络对应、3MF 单位为 mm，板框包含六个闭合轮廓。USB-C 的 STL 包含整只母座；RGB 在 3MF 中使用封闭外包络，原始细节网格只用于 HTML 预览。

[浏览器报告](review/browser-checks.json) 验证器件来源与原始三角面数量、六个端子及四个固定脚、PCB 装配视图、离线加载、无脚本错误、梯形端面、顶角凹口、下盖配合、LED 位置及三点固定坐标、正面/背面/特写、爆炸、透明、图层、剖切、未缩放原型对照、两段运动、STL 下载及移动屏幕横向排版。截图保存在 `review`。

本版完成机械几何评审，尚未实物试装。没有进行结构强度、疲劳、打印收缩、LED 混色、按键材料变形或电气/RF 验证。

## 尺寸资料

- [韩荣 K2-1831SL 官方系列页](http://www.krhro.com/Product-Details/142.html)；[官方 A4SW 尺寸 PDF](http://omo-oss-file110.thefastfile.com/portal-saas/pg2026081913505947704/cms/file/k2-1831sl%283%29.pdf)。
- [星坤 TS-1101-C-W 厂家尺寸图](https://datasheet.lcsc.com/datasheet/pdf/588e2cdf2775df050133e65c68ada42d.pdf?productCode=C318938)。
- [韩下 HX TYPE-C 6P QTWT 厂家尺寸图](../reference/component-models/C18357553.pdf)。
- [EEMB LP402535 厂商页](https://eemb.store/products/lp402535)。
- [Nordic nRF52832 封装信息](https://docs.nordicsemi.com/r/bundle/ps_nrf52832/page/ordering_info.html)。

### 2026-09-23 最终 PCB 同步

上方孔由 (0,28) 移至 (14,28)，孔径 2.30 mm。数据来自 Chrome 当前文档的 API 只读导出，三个孔的图元 ID 和坐标保存在 `scripts/layout.json` 的 `pcb_source`。用户于 2026-09-24 确认实际下单板厚 1.6 mm。PCB 上表面保持 -7.45，底面下移到 -9.05，底装 USB 开孔中心同步下移 0.60 mm。

USB 库模型原点相对于封装原点有 Y=-1.38194 mm 的偏移，已显式校正，并逐一与最终 PCB 的十个实际焊盘中心比对，误差小于 0.004 mm。

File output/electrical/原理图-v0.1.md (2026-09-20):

# nRF52832 Canon 遥控器：文字原理图 v0.1

更新日期：2026-09-20。用于转绘原理图和开始 PCB 规划；遥控器本板尚未完成 EDA ERC、PCB layout、射频调试或样机验证。

[查看 7 页图形原理图](schematic-drawing-v0.1.html)：含元件符号、引脚编号、数值和 layout 注释，与本文同步更新。BAT54H 厂商脚号为 2=阳极、1=阴极。

2026-09-19：图纸已逐器件补充 `JLC C…` 物料编号，未确定编号的器件、DNP 位置与自带焊盘也分别标注。编号及采购状态见 [完整 BOM](BOM-v0.1.md)。

2026-09-20：按用户已有开发板的用值反馈，HF、LF 晶振两侧均采用各一颗 12 pF 对地电容，合计四颗；后续 200 段电容位号顺延，具体对应见 3.2 节。

2026-09-20 按键简化：删除 R300～R308、C300～C308 共 18 个元件，9 路触点直接连接 GPIO，使用内部上拉与固件去抖；连接统一使用 `KEY_*` 网络名。

本版对应目前的机械方案：四向圆环、中心 K2-1831SL-A4SW-01 两段键、下排三个圆键、NH-B1515RGBA-GF RGB、HX TYPE-C 6P QTWT 和单节软包锂电池。7 个普通开关 + 1 个两段开关，共 **9 路按键信号**。主控选 **nRF52832-QFAA，QFN48，6 × 6 mm**，不使用 WLCSP 的引脚表。

建议转绘为五页：① USB／充电／电源；② MCU／时钟；③ 按键／RGB；④ RF／天线；⑤ SWD／测试点。相同网络名直接相连。下文所有 `GND` 属于同一电气网络，`NC` 是不连接，`DNP` 是保留焊盘但首版不装。

## 1. 总体结构与电源网络

```mermaid
flowchart LR
  USB[USB-C 6Pin / 5 V] --> CHG[MSTP4054-42 / 100 mA]
  CHG --> BAT[1S 带保护软包电池]
  USB --> D[肖特基二极管]
  D --> SYS[VSYS]
  BAT --> PMOS[P-MOS 电池通路]
  PMOS --> SYS
  USB -. 插线时关闭电池通路 .-> PMOS
  SYS --> LDO[ME6211 / 3.3 V]
  LDO --> VDD[VDD / R104 后]
  VDD --> MCU[nRF52832-QFAA]
  VDD --> RGB[共阳 RGB / 每色独立限流]
  MCU -. GPIO 低有效 / PWM .-> RGB
  KEY[7 个单段 + 1 个两段开关] --> MCU
  SWD[1 VDD / 2 GND / 3 IO / 4 CLK] <--> MCU
  MCU --> RF[Nordic RF 参考网络]
  RF --> MATCH[天线匹配预留]
  MATCH --> ANT[KH-2012-HM1]
```

| 网络 | 含义／允许连接 |
| --- | --- |
| `VBUS_5V` | USB 输入；连接充电器、USB 电源通路和 USB 检测 MOS 的栅极电路 |
| `VBAT` | **电池保护板输出 P+**；满电约 4.2 V，不能直连 MCU VDD |
| `VSYS` | 切换后的系统电源；电池时接近 VBAT，USB 时约为 VBUS 减去二极管压降 |
| `VREG_3V3` | ME6211 输出，经过 R104 到 VDD |
| `VDD` | MCU／GPIO 与 RGB 共阳电源，正常约 3.3 V；低电量时可能低于 3.3 V |
| `DEC1` / `DEC3` / `DEC4` | MCU 内部电源节点；仅连接指定无源件，不能给外部器件供电 |

USB 口用于供电和充电。该 6Pin 接口没有 USB 数据线；nRF52832 也没有原生 USB 控制器。

## 2. USB-C、充电与供电切换

### 2.1 J100：HX TYPE-C 6P QTWT

采用自购的 6Pin 全贴母座，对应 C18357553。[厂家图纸](../../reference/component-models/C18357553.pdf)与库封装一起复核，不使用之前 16Pin 型号的焊盘编号。

| J100 引脚／焊盘 | 连接 |
| --- | --- |
| A9、B9 | `VBUS_5V`，两脚都接 |
| A12、B12 | `GND`，两脚都接 |
| A5 / CC1 | `USB_CC1` |
| B5 / CC2 | `USB_CC2` |
| 金属壳焊脚（现有库编号 17～20） | `GND` |

```text
R100  5.1k  1% 0402 : USB_CC1 — GND          [C25905]
R101  5.1k  1% 0402 : USB_CC2 — GND          [C25905]
C100  100nF 16V 0402: VBUS_5V — GND         [C60474]
D101  PESDNC2FD5VB  : VBUS_5V — GND         [C5356109，双向 ESD]
D102  PESDNC2FD5VB  : USB_CC1 — GND         [C5356109，双向 ESD]
D103  PESDNC2FD5VB  : USB_CC2 — GND         [C5356109，双向 ESD]
```

CC1、CC2 **各自一个** 5.1 kΩ 下拉，不能短接后共用一个。D101～D103 用于 ESD，不构成持续过压保护。本版不做 PD 升压请求，按 5 V 电源使用，正常总耗电目标小于 150 mA。

**Layout 注释：** ESD 紧邻接口，接口引出的线先经过保护器件连接点再进入板内；ESD 地焊盘旁放就近地过孔。USB 金属壳焊盘提供机械固定与短的接地路径。板舌、焊耳与下盖开口继续沿用已确认的机械定位。不要在 USB 输入处随意增加大电容；后续检查插拔浪涌和 USB 输入电容量。

### 2.2 U100：MSTP4054-42，SOT23-5L

| 引脚 | 名称 | 连接 |
| --- | --- | --- |
| 1 | CHRG | `CHG_N` |
| 2 | GND | `GND` |
| 3 | BAT | `VBAT` |
| 4 | VCC | `VBUS_5V` |
| 5 | PROG | `CHG_PROG` |

```text
U100  MSTP4054-42                               [C49208527]
C101  2.2uF 6.3V 0603 : VBUS_5V — GND           [C5137560]
C102  1uF   16V  0603 : VBAT — GND              [C1592]
R105  10k 1% 0402     : CHG_PROG — GND          [C2906861]
R106  10k 1% 0402     : VDD — CHG_N             [C2906861]
CHG_N                : U100.1 — U200.21/P0.18
```

厂商给出的设置关系为 `I_CHG(A) = 1000 / R_PROG(Ω)`，所以 **10 kΩ → 100 mA**；针对当前 320 mAh 电池候选，约为 0.31C。若最终电池允许电流更小，换库存 12 kΩ 可降至约 83 mA，或进一步增大阻值。以最终电池手册的充电电流和温度范围为准。

该手册“功能描述”写充电终止为设定电流的 15%，另一段又写 PROG 低于 100 mV；两处不完全一致。首版按 100 mA 恒流设计，**实际终止电流须实测，不承诺固定 10 mA 或 15 mA**。`CHG_N=0` 表示正在充电；高电平也可能是没有 USB、未接电池或停充，须联合 `USB_PRESENT_N` 判断，不能单凭它显示“电池已充满”。[依据：MSTP4054-42 手册第 3～7 页](../../reference/electrical/MSTP4054-42.pdf)。

**电池接口 J101：** 两个焊线焊盘 `1=VBAT(P+)`、`2=GND(P−)`，旁边印 `+` / `−`，优先软线连接以节省高度。必须使用 **1S、4.2 V 充电、带过充／过放／短路保护**的软包电池。当前 LP402535 只是尺寸／容量候选，尚未确认购买版本是否带保护。若买裸电芯，必须增加保护电路后再使用本图的 J101。MSTP4054 本身不是电芯保护板，也没有电池 NTC 输入。

**Layout 注释：** C101 放 U100.4 旁，C102 放 U100.3 旁；PROG 电阻紧邻 U100.5，其地回到 U100.2 附近。充电电流路径留足线宽并铺地散热，远离晶体、天线和 ADC。100 mA、VBAT=3 V、VBUS=5 V 时芯片发热约 0.2 W；仍需装壳充电测温，不能用内部芯片热调节替代电池温度管理。

### 2.3 USB／电池自动切换

```text
D100  BAT54H，Nexperia，SOD123F，新增：
      2/A/阳极 = VBUS_5V
      1/K/阴极 = VSYS（器件标记条一侧）

Q100  AO3401A，P-MOS，SOT23，新增：
      1/G = BAT_PATH_GATE
      2/S = VSYS
      3/D = VBAT

R102  0Ω 0402  : VBUS_5V — BAT_PATH_GATE        [C2906858]
R103  10k 0402 : BAT_PATH_GATE — GND            [C2906861]
```

Q100 的 **D 接电池、S 接系统**，这是本电路的有意安排：体二极管方向为 `VBAT → VSYS`，USB 供电时阻止 VSYS 向电池直接灌电。插入 USB 后 Q100 关断，系统由 D100 供电，电池只通过 U100 充电；拔线后 R103 拉低栅极，Q100 导通，由电池供电。库存 SI2302 是 **N-MOS**，不能替代 Q100；库存 1N4148WS 也不是这里指定的肖特基。

D100 只承担系统负载，不经过 100 mA 充电电流；本版系统峰值按不超过约 30 mA 规划，BAT54H 的电流规格够用。其反向漏电会影响休眠，拔线及高温时实测。USB 电压下跌时电池可能经体二极管短暂补电，这不是完整的集成 power-path 控制器；检查插拔过程与 MCU 复位情况。[AO3401A](https://www.aosmd.com/pdfs/datasheet/AO3401A.pdf)、[BAT54H](https://assets.nexperia.com/documents/data-sheet/BAT54H.pdf)。

**Layout 注释：** D100、Q100 与 LDO 输入放在一起。VBAT 充电支路和系统支路在电池接口附近分开；不要让系统大电流从充电芯片 BAT 引脚焊盘上绕行。Q100 栅极不悬空，R103 靠近栅极。

### 2.4 U101：ME6211C33M5G-N，3.3 V LDO

| 引脚 | 名称 | 连接 |
| --- | --- | --- |
| 1 | VIN | `VSYS` |
| 2 | VSS | `GND` |
| 3 | CE | `VSYS`，常开 |
| 4 | NC | 不连接 |
| 5 | VOUT | `VREG_3V3` |

```text
U101  ME6211C33M5G-N                           [C82942]
C103  1uF 16V 0603 : VSYS — GND                [C1592]
C104  1uF 16V 0603 : VREG_3V3 — GND            [C1592]
R104  0Ω 0402     : VREG_3V3 — VDD             [C2906858]
```

R104 可拆下串入电流表测 VDD 电源支路，包含 MCU 和 GPIO 直驱 RGB 的电流；整机电流应在实际供电入口另测，电池模式在电池入口测量。SWD 的 VDD 默认只作调试器电压参考，板子自行供电，避免调试器电源与 LDO 输出相互驱动。

ME6211 输入不能直接换成电池后再省掉稳压，因为 nRF52832 的 VDD 上限为 3.6 V，4.2 V 电池会超限。低电量时 LDO 进入压差区，VDD 不再保持 3.3 V，但仍可在 nRF52832 工作范围内运行；固件建议在约 3.2 V 电池电压时提示低电，约 3.0 V 时进入休眠，实际门限按电池与负载调试。

**待机取舍：** ME6211 首页标 40 µA 典型，C33 电气表标 60 µA 典型，首版功耗预算按较高的 60 µA。仅这一项已使 320 mAh 电池的理想时间约为 222 天，尚未扣除其他负载、自放电和不可用容量；不能据此宣称多年续航。若目标是很长的闲置时间，下一版优先换低静态电流 LDO。[ME6211 手册，第 4、8 页](../../reference/electrical/ME6211.pdf)。

**Layout 注释：** C103 靠 VIN/GND、C104 靠 VOUT/GND，回路短，输出电容不能省略。R104 位于 C104 后；MCU 本地去耦位于 R104 的 VDD 侧。1 µF 的实际有效容量需要考虑 MLCC 直流偏压，不只看标称值。

### 2.5 USB 检测与电池测量

```text
Q101  SI2302，N-MOS SOT23 [C2891732]：
      1/G = USB_GATE ; 2/S = GND ; 3/D = USB_PRESENT_N
R107  10k 0402 : VBUS_5V — USB_GATE             [C2906861]
R108  1M  0603 : USB_GATE — GND                [C49196763]
R109  10k 0402 : VDD — USB_PRESENT_N            [C2906861]
USB_PRESENT_N : U200.22/P0.19；有 USB 时为低

R110  1M 1% 0603 : VBAT — VBAT_SENSE           [C49196763]
R111  1M 1% 0603 : VBAT_SENSE — GND            [C49196763]
C105  100nF 0402 : VBAT_SENSE — GND            [C60474]
VBAT_SENSE      : U200.4/P0.02/AIN0
```

USB 检测经 MOS 隔离电压，**VBUS 不直接进入 GPIO**。电池分压比为 1/2，满电 ADC 输入约 2.1 V；分压常耗约 2.1 µA。SAADC 使用内部 0.6 V 参考、增益 1/6、单端、采集时间 40 µs，关闭该脚数字输入缓冲与上下拉。等效源阻约 500 kΩ；40 µs 对应的 Nordic 最大源阻为 800 kΩ。C105 的 RC 时间常数约 50 ms，上电至少等约 250 ms 再读，平时低频采样，勿连续高速采样。[SAADC 依据](https://docs.nordicsemi.com/r/bundle/ps_nrf52832/page/saadc.html)。

**Layout 注释：** R110/R111/C105 靠 ADC 输入，避开 RF、DCC 和 LED PWM 走线。R104 拆开、MCU 未供电时，VBAT_SENSE 仍可能通过输入保护结构产生微小反灌；调试外部供电前先断开电池，不能把 R104 当作全机电气隔离开关。

## 3. nRF52832 主控最小系统

U200 使用 nRF52832-QFAA。以下接线以 Nordic QFAx 参考设计 v1.1 为基础；原版 [参考原理图](../../reference/electrical/nrf52832_qfaa_dcdc_schematic.pdf)和 [参考 PCB](../../reference/electrical/nrf52832_qfaa_dcdc_pcb.pdf)已归档。电源和 RF 区尽量保留其相对布局。

### 3.1 电源、内部稳压及复位

```text
U200.13/VDD = VDD     C203 100nF 0402 : VDD — GND，靠 pin 13 [C60474]
U200.36/VDD = VDD     C204 100nF 0402 : VDD — GND，靠 pin 36 [C60474]
U200.48/VDD = VDD     C205 4.7uF 0402 : VDD — GND，靠 pin 48 [C46635918]
                      C206 100nF 0402 : VDD — GND，靠 pin 48 [C60474]

U200.31/VSS = GND
U200.45/VSS = GND
U200.EP     = GND     裸露中心焊盘必须接地，不得悬空

U200.1/DEC1 = DEC1    C200 100nF 0402 : DEC1 — GND [C60474]
U200.32/DEC2 = NC     本 QFN48 版本不装 DEC2 电容，不接 VDD/GND
U200.33/DEC3 = DEC3   C201 100pF C0G 0402 : DEC3 — GND [C46614473]
U200.46/DEC4 = DEC4   C202 1uF 0603 : DEC4 — GND [C1592]
U200.44/NC = NC

U200.47/DCC — L200(10uH) — DCDC_MID — L201(15nH) — DEC4
L200 = TDK MLZ1608M100WT000，0603，新增
L201 = SDCL1005C15NKTDF，0402，库存 C370189

U200.24/P0.21/nRESET = RESET_N
R200 10k 0402 : VDD — RESET_N [C2906861]
TP205 = RESET_N，单独测试焊盘

U200.37/P0.25 — C214(12pF C0G 0402) — GND [C45359894]
U200.38/P0.26 — C215(12pF C0G 0402) — GND [C45359894]
```

C214/C215 沿用 v1.1 参考图对 errata 138 的处理，这两脚本版不分配其他功能。不要把 **GPIO P0.25/P0.26** 与 **封装 pin 25/26（SWD）** 混淆。[Nordic PCB 指南](https://devzone.nordicsemi.com/guides/hardware-design-test-and-measuring/b/nrf5x/posts/nrf52832-specific-pcb-guidelines)。复位功能需要固件正确配置 `UICR.PSELRESET`。

**DC/DC 选件：** Nordic 要求 10 µH 电感额定电流至少 50 mA；库存 C411950 / SCL1608S100KSP 的规格只有 3 mA，不采用。L200 选用额定电感变化电流 90 mA 的 [TDK MLZ1608M100WT000](https://product.tdk.com/en/search/inductor/inductor/smd/info?part_no=MLZ1608M100WT000)。装好 L200/L201 后固件开启 DC/DC。若先用内部 LDO 调试，两颗电感均 DNP、DCC 悬空，C202 保留，并保持 `DCDCEN=0`；不要把 DCC 短接到 VDD。

库存去耦有两处与参考 BOM 不同：C205 为 0402/±20%，Nordic 原版是 0603/±10%；C202 库存为 X5R，原版为 X7R。首版可以先按上述库存画图，但采购／投板前核对有效容量、温度范围及封装，必要时换回参考规格；**不能仅因容量字样相同就认为完全等效**。

**Layout 注释：**

- C200、C201、C202 分别紧邻对应 DEC 脚，电容到芯片的线短，电容接地就近落过孔；不要把三个 DEC 网络连接在一起。
- C203/C204 不共享一条长去耦支线。电源先到对应电容连接点，再到 VDD 脚；参考布局优先于机械式套用“必须某个方向进线”。
- L200/L201/C202 形成紧凑回路，DCC 开关节点不铺大铜、不绕到晶体或天线下面。10 µH → 15 nH 的顺序保持参考电路。
- 裸露焊盘与 GND 平面可靠连接，使用适量接地过孔并按装配能力处理阻焊／塞孔，避免焊锡被过孔吸走。
- C214/C215 紧邻 pin 37/38，不延长到板外测试点。

### 3.2 32 MHz 与 32.768 kHz 时钟

```text
X200 = YE32MDBCD2X，32MHz，CL=10pF，2016-4P [C54427949]
X200.1 — U200.34/XC1
X200.3 — U200.35/XC2
X200.2、X200.4 — GND

C210 12pF C0G 0402 : XC1 — GND [C45359894]
C211 12pF C0G 0402 : XC2 — GND [C45359894]

X201 = KFC3276812520T，32.768kHz，CL=12.5pF，3215-2P [C18209174]
X201.1 — U200.2/P0.00/XL1
X201.2 — U200.3/P0.01/XL2

C212 12pF C0G 0402 : XL1 — GND [C45359894]
C213 12pF C0G 0402 : XL2 — GND [C45359894]
```

两组晶振各有两颗负载电容，每个晶振端各接一颗 12 pF 到地，全部使用库存 C45359894。用值依据是用户已有开发板的反馈；原有的额外负载电容已删除。

晶体的标称 CL 保持原型号参数，外接电容值为每侧 12 pF，两者含义不同。遥控器 PCB 的起振与频偏在本板验证。参考：[Nordic 时钟规格](https://docs.nordicsemi.com/r/bundle/ps_nrf52832/page/clock.html)、[X200 手册](../../reference/electrical/YE32MDBCD2X.pdf)、[X201 手册](../../reference/electrical/KFC3276812520T.pdf)。

本次位号调整如下（“旧位号”指 2026-09-19 图纸）：

| 用途 | 旧位号 | 当前位号／数值 |
| --- | --- | --- |
| HF，XC1 对地 | C210 | C210，12 pF |
| HF，XC2 对地 | C212 | C211，12 pF |
| LF，XL1 对地 | C214 | C212，改为 12 pF |
| LF，XL2 对地 | C216 | C213，改为 12 pF |
| P0.25 杂散抑制 | C218 | C214，12 pF |
| P0.26 杂散抑制 | C219 | C215，12 pF |
| 芯片端 RF 对地 | C220 | C216，0.8 pF |
| 天线匹配预留 | C221、C222 | C217、C218，DNP |

旧 C211、C213、C215、C217 四个额外负载电容位置删除。C300～C308 已随按键直连修改删除；RGB 电路电容保留分组编号 C400。

X200 的库存条目指定 10 pF，所附厂商 PDF 是系列通用表；其 1/3 晶体端、2/4 接地的引脚图已核对。量产前锁定完整订购参数，检查初始误差、温漂、老化及电容拉偏的总误差满足 BLE ±40 ppm。X201 的 ±20 ppm 是室温初始值，固件 LFCLK 精度配置须包含工作温度漂移，不能直接填 20 ppm。

**Layout 注释：** 晶体和负载电容紧贴对应引脚，同层、短线、少过孔，晶体回路下不走 DCC/PWM/SWD 等信号。接地环与地平面按 Nordic 参考布局组织，避免新增大寄生。不要在晶体线上放长支路测试点，也不要直接用普通高电容示波器探头判断其工作频率；采用时钟输出或射频频偏测试。

## 4. 按键

全部采用独立 GPIO 输入，低电平有效，使用 MCU 内部上拉；可配置低电平 GPIO SENSE 唤醒。没有矩阵扫描，中心两段可以独立检测。

每路通用接法如下，GPIO 与触点属于同一个 `KEY_*` 网络：

```text
U200.GPIO（输入，开启内部上拉）── KEY_* ── 开关触点 ── GND
```

R300～R308 和 C300～C308 已删除，不保留为 DNP。松开为高电平，按下为低电平。固件必须开启每路内部上拉，并对按下、松开各自去抖；先采用 **5～15 ms** 的稳定时间，再根据实物调整。中断／唤醒后重新采样确认状态，半按与全按分别处理。[nRF52832 GPIO 依据](https://docs.nordicsemi.com/r/bundle/ps_nrf52832/page/gpio.html)。

| 开关／触点 | 功能 | 直连网络 | GPIO／QFN 脚 |
| --- | --- | --- | --- |
| S300 | 圆环上 | KEY_UP | P0.04 / 6 |
| S301 | 圆环下 | KEY_DOWN | P0.05 / 7 |
| S302 | 圆环左 | KEY_LEFT | P0.06 / 8 |
| S303 | 圆环右 | KEY_RIGHT | P0.07 / 9 |
| S304 | 下排左圆键 | KEY_AUX1 | P0.08 / 10 |
| S305 | 下排中圆键 | KEY_AUX2 | P0.11 / 14 |
| S306 | 下排右圆键 | KEY_AUX3 | P0.12 / 15 |
| S307.a / SW1 | 中心半按 | KEY_HALF | P0.16 / 19 |
| S307.b / SW2 | 中心全按 | KEY_FULL | P0.17 / 20 |

S300～S306 为 TS-1101-C-W（C318938），两电气端分别接对应 `KEY_*` 与 GND。S307 是 **一颗 K2-1831SL-A4SW-01**，不是两颗普通开关：

```text
S307 的 c 公共端（两个 c 焊脚） → GND
S307 的 a / 第一段触点         → KEY_HALF
S307 的 b / 第二段触点         → KEY_FULL
两个定位孔                    → NPTH，无电气连接
```

按 [HRO 图纸](../review/k2-1831sl-datasheet.pdf) 的 `a/b/c` 标识建符号；若库符号使用数字脚号，须明确填写数字与字母对应，不按普通四脚轻触的“两两短接”方式猜测。预计半按第一段闭合、全按两段闭合；用实物通断测试确认时序后再确定固件事件处理。板上 a/b 的方向以厂家焊盘视图为准，注意与顶视图的镜像关系。

**Layout 注释：** 开关首先服从键帽顶柱和中心开关定位孔的机械位置。按键走线尽量短，与 RF 馈线、晶体和 DCC 保持距离，并保证连续地参考。不要让开关回地跨过晶体或 RF 的局部接地区。按键持续按住时内部上拉会耗电，休眠策略需处理被压住的按键。

## 5. RGB LED：NH-B1515RGBA-GF

D400 选库存 C52212029。厂家引脚为 **2 共阳、1 红阴极、3 蓝阴极、4 绿阴极**，不是按 R/G/B 顺序依次编号。[引脚依据：手册第 6 页](../../reference/electrical/NH-B1515RGBA-GF.pdf)。

RGB 改用 **GPIO 直接灌电流驱动**：共阳接 MCU 同一条 **VDD（R104 后）**，三个阴极分别经独立限流电阻接 GPIO。共阳不能再接 VSYS 或 VBAT，以免 GPIO 承受高于自身电源的电压。Q400～Q402、R403～R408 已删除，不保留为 DNP；共减少 9 件物料。保留 R400～R402 位号与库存料号，按 3.3 V 供电重新估算电流。

```text
D400.2/共阳 = VDD
C400 100nF 16V 0402 : VDD — GND [C60474]

D400.1/R阴极 — R400(1.2k 0402, C2909307) — LED_R_PWM / U200.16 / P0.13
D400.4/G阴极 — R401(1k   0402, C106235)   — LED_G_PWM / U200.17 / P0.14
D400.3/B阴极 — R402(1k   0402, C106235)   — LED_B_PWM / U200.18 / P0.15
```

**固件配置：** GPIO **低电平点亮、高电平熄灭**，与旧 MOS 方案的极性相反。P0.13／P0.14／P0.15 均使用 `DRIVE=H0S1`（低电平高驱动、高电平标准驱动）、无上下拉、断开输入缓冲、禁用 SENSE。初始化先用 `OUTSET` 将这三位预置为 1，再启用输出，避免初始输出 0 导致闪亮。PWM 采用低有效，亮度占空比指低电平占空比；停止 PWM、交还 GPIO 控制后恢复输出 1，休眠前关闭指示灯。

Nordic 的标准驱动低电平规格以 0.5 mA 为条件；高驱动在 VDD≥2.7 V 时以 5 mA、VDD≥1.7 V 时以 3 mA 保证 `VOL≤0.4 V`。本方案按小电流指示设计，仍选 H0S1 留出余量，不能用 PWM 平均电流替代导通瞬间电流检查。[GPIO 驱动与电气规格](https://docs.nordicsemi.com/r/bundle/ps_nrf52832/page/gpio.html)。

电流估算式为 `I≈(VDD−Vf−VOL)/R`。VDD=3.3 V、先忽略 VOL，采用手册 R/G/B 典型 Vf=2.0/2.7/2.8 V 粗估，约为 **1.1/0.6/0.5 mA**。这些 Vf 分别是在 8/5/3 mA 下测得，并非本电路低电流时的保证值；实际电流、混色和导光后亮度须实测。电阻限流不提供恒流，电池低压导致 VDD 下降时，尤其绿／蓝通道可能明显变暗甚至不满足可见亮度。[LED 电气表：手册第 3 页](../../reference/electrical/NH-B1515RGBA-GF.pdf)。

充电指示仍由 MCU 读取 `CHG_N` 与 `USB_PRESENT_N` 后控制 RGB；该接法不提供 MCU 断电时的独立充电指示。

**Layout 注释：** D400 按导光件位置固定，C400 贴近 LED 的 VDD／GND；三个限流电阻靠近 LED 放置。LED 供电从 R104 后 VDD 引入，GPIO 灌电流经 MCU 地脚回流，使用连续地平面并缩短回路；避免 LED 电流与 RF 匹配电容、晶体区域共用狭窄回流路径。PWM 走线避开天线与晶体，初期用几百 Hz 至约 1 kHz。

## 6. RF 与陶瓷天线

ANT200 使用库存 **KH-2012-HM1 / C2925419**。厂商定义 **pin 1=INPUT，pin 2=NC**；第二焊盘仅按图纸机械焊接，不接地、不连接到其他网络。

```text
                         L220 3.9nH
U200.30/ANT ── RF_ANT ─────LLLL───── RF_50 ── R221(0Ω) ── ANT_FEED ── ANT200.1
                  │                   │                      │
              C216 0.8pF          C217 DNP               C218 DNP
                  │                   │                      │
                 GND                 GND                    GND

ANT200.2 = NC
```

| 位号 | 本版值／封装 | 来源／作用 |
| --- | --- | --- |
| C216 | 0.8 pF，C0G/NP0，0402，精度按参考要求选 | 新增，**位于 MCU ANT 侧**，不是电感远端 |
| L220 | 3.9 nH，高 Q 射频电感，0402，±5% | 新增；库存 3.0 nH 不直接替换 |
| C217、C218 | DNP，0402，预留 C0G 电容或高频电感 | 天线调谐并联臂，数值 TBD |
| R221 | 0 Ω 0402 | 库存 C2906858；调谐时可替换为串联电感／电容 |
| ANT200 | KH-2012-HM1，2.0 × 1.2 × 0.5 mm | 库存 C2925419 |

**分清两个网络：** C216/L220 是 Nordic QFN48 的参考射频网络，本版先保留参考初值；C217/R221/C218 才是陶瓷天线的匹配预留，按你的要求暂不计算。厂商天线示例板为 90 × 50 mm，不能把它的 1.5 pF／0.7 pF 数值当作本遥控器最终匹配；库存这两种值可留作调试备料。[Nordic 参考电路](https://docs.nordicsemi.com/r/bundle/ps_nrf52832/page/ref_circuitry.html)、[天线手册第 2～3 页](../../reference/electrical/KH-2012-HM1.pdf)。

**Layout 注释：**

- C216/L220 与 U200 的相对位置、接地方式尽量照参考 PCB；ANT → C216 → L220 这段不是可以随意拉长的 50 Ω 线。C216 地端紧靠 U200.31/VSS 与中心接地，采用短、低电感回路。
- 从 `RF_50` 开始到天线匹配区，按实际板厚／叠层计算 50 Ω 馈线；不要先指定一个通用线宽。地参考连续，不跨分割或开槽，旁边地过孔围栏不能侵入天线净空。
- 天线朝板边放置，按厂家第 2 页的焊盘、馈入方向和地开窗复刻其局部布局。该图含毫米级地开窗（约 5 × 4 mm 量级），不是仅给 2 × 1.2 mm 器件本体留空。最终 keepout 尺寸需在 PCB 图中按厂家坐标明确标注。
- 天线辐射净空区各层不铺铜、不走线，只有厂家规定的馈线／焊盘结构；馈线区则需要参考地，两者不要混淆。NC 焊盘保持孤立。
- 天线远离软包电池铝膜、USB 壳、SWD 排针、螺丝以及金属开关。当前 3D 模型尚未安放本版天线和全部电源器件，必须重新做实体位置检查；机械 PCB 外形不等于已完成 RF 布局。
- 实板装上电池、外壳、导光件，并考虑手握状态后再调天线。匹配区留可拆串联位 R221，便于断开 MCU 做测量；不要无故增加长支路 SMA 测试线。

## 7. J200：4Pin SWD

**单排 1×4，2.54 mm，固定顺序如下：**

| 连接器脚号 | 丝印 | 网络／连接 |
| --- | --- | --- |
| 1 | VDD | `VDD`，调试电压参考 |
| 2 | GND | `GND` |
| 3 | IO | `SWDIO` → U200.26/SWDIO |
| 4 | CLK | `SWDCLK` → U200.25/SWDCLK |

第一版直接连接，不在 CLK/IO 上加大电容。调试器启用目标电压检测，板子由电池或 USB 正常供电；**不向 pin 1 施加 5 V**。RESET_N 留独立 TP205，四针顺序不变。

**Layout 注释：** pin 1 用方焊盘和三角标记，丝印直接标 `1:V / 2:G / 3:IO / 4:CK`。排针只装调试样机，日常版本可空焊盘配探针，避免高度干涉；这个 2.54 mm 接口尚未反映在当前外壳模型中。SWD 走线短、带地参考，远离天线净空与晶体。

测试点建议：TP200=VDD，TP201=GND，TP202=VBUS_5V，TP203=VBAT，TP204=VSYS，TP205=RESET_N，TP206=CHG_N，TP207=USB_PRESENT_N。不要在 DEC／晶体／ANT 节点新增长测试支线。

## 8. U200 完整引脚分配表

| QFN 脚 | 芯片功能 | 本版连接 |
| --- | --- | --- |
| 1 | DEC1 | DEC1，C200 到地 |
| 2 | P0.00/XL1 | X201.1，C212 12 pF 到地 |
| 3 | P0.01/XL2 | X201.2，C213 12 pF 到地 |
| 4 | P0.02/AIN0 | VBAT_SENSE |
| 5 | P0.03/AIN1 | NC，备用 |
| 6 | P0.04 | KEY_UP |
| 7 | P0.05 | KEY_DOWN |
| 8 | P0.06 | KEY_LEFT |
| 9 | P0.07 | KEY_RIGHT |
| 10 | P0.08 | KEY_AUX1 |
| 11 | P0.09/NFC1 | NC，保留默认 NFC 配置 |
| 12 | P0.10/NFC2 | NC，保留默认 NFC 配置 |
| 13 | VDD | VDD，C203 |
| 14 | P0.11 | KEY_AUX2 |
| 15 | P0.12 | KEY_AUX3 |
| 16 | P0.13 | LED_R_PWM，经 R400 到红阴极，低有效 |
| 17 | P0.14 | LED_G_PWM，经 R401 到绿阴极，低有效 |
| 18 | P0.15 | LED_B_PWM，经 R402 到蓝阴极，低有效 |
| 19 | P0.16 | KEY_HALF |
| 20 | P0.17 | KEY_FULL |
| 21 | P0.18 | CHG_N |
| 22 | P0.19 | USB_PRESENT_N |
| 23 | P0.20 | NC，备用 |
| 24 | P0.21/nRESET | RESET_N |
| 25 | SWDCLK | J200.4 |
| 26 | SWDIO | J200.3 |
| 27 | P0.22 | NC，备用 |
| 28 | P0.23 | NC，备用 |
| 29 | P0.24 | NC，备用 |
| 30 | ANT | RF_ANT |
| 31 | VSS | GND |
| 32 | DEC2 | NC，QFN 不装去耦 |
| 33 | DEC3 | DEC3，C201 到地 |
| 34 | XC1 | X200.1，C210 12 pF 到地 |
| 35 | XC2 | X200.3，C211 12 pF 到地 |
| 36 | VDD | VDD，C204 |
| 37 | P0.25 | C214 12 pF 到地，无其他负载 |
| 38 | P0.26 | C215 12 pF 到地，无其他负载 |
| 39 | P0.27 | NC，备用 |
| 40 | P0.28/AIN4 | NC，备用 |
| 41 | P0.29/AIN5 | NC，备用 |
| 42 | P0.30/AIN6 | NC，备用 |
| 43 | P0.31/AIN7 | NC，备用 |
| 44 | NC | 不连接 |
| 45 | VSS | GND |
| 46 | DEC4 | DEC4，C202 和 L201 |
| 47 | DCC | L200 输入 |
| 48 | VDD | VDD，C205/C206 |
| EP | 裸露中心焊盘 | GND；若库编号 49，核实其确为 EP |

未使用 GPIO 保持输入断开、无上拉／下拉，不输出快速信号。尤其靠 RF 一侧的空闲 GPIO 不随意改成高速接口。[引脚依据](https://docs.nordicsemi.com/r/bundle/ps_nrf52832/page/pin.html)。

## 9. 首版 BOM 与库存对应

按所属电路、具体作用和已有／待采购状态拆分的完整表格见 **[完整电气 BOM v0.1](BOM-v0.1.md)**。下面保留按料号合并的单板用量汇总。

下表数量是单板默认装配数，晶体负载电容共四颗，不含 DNP 和测试焊盘。原始订单是购入记录，实际剩余库存仍以实物为准。

| 物料号／来源 | 规格 | 数量 | 位号 |
| --- | --- | ---: | --- |
| C77540，待采购 | nRF52832-QFAA / NRF52832-QFAA-R | 1 | U200 |
| C49208527 | MSTP4054-42 | 1 | U100 |
| C82942 | ME6211C33M5G-N | 1 | U101 |
| 淘宝自购；C18357553 对应型号 | HX TYPE-C 6P QTWT | 1 | J100 |
| 新增／选定实物 | 1S 带保护软包，候选 320 mAh | 1 | J101 外接电池 |
| 新增 | 1×4 2.54 mm SWD 排针／焊盘 | 1 | J200 |
| C15127，待采购 | AOS AO3401A / P-MOS / SOT23 | 1 | Q100 |
| C426769，待采购 | Nexperia BAT54H,115 / SOD123F | 1 | D100 |
| C2891732 | SI2302 / N-MOS / SOT23 | 1 | Q101 |
| C5356109 | PESDNC2FD5VB / DFN1006-2 | 3 | D101～D103 |
| C54427949 | 32 MHz / YE32MDBCD2X | 1 | X200 |
| C18209174 | 32.768 kHz / KFC3276812520T | 1 | X201 |
| C76798，待采购 | 10 µH / MLZ1608M100WT000 / 0603 | 1 | L200 |
| C370189 | 15 nH / SDCL1005C15NKTDF / 0402 | 1 | L201 |
| 新增 | 3.9 nH RF，±5%，0402 | 1 | L220 |
| 新增 | 0.8 pF C0G，0402，精度按 Nordic 要求 | 1 | C216 |
| C2925419 | KH-2012-HM1 天线 | 1 | ANT200 |
| C318938 | TS-1101-C-W | 7 | S300～S306 |
| 手工记录 | K2-1831SL-A4SW-01 | 1 | S307 |
| C52212029 | NH-B1515RGBA-GF | 1 | D400 |
| C25905 | 5.1 kΩ 1% 0402 | 2 | R100、R101 |
| C2906858 | 0 Ω 0402 | 3 | R102、R104、R221 |
| C2906861 | 10 kΩ 1% 0402 | 6 | R103、R105、R106、R107、R109、R200 |
| C49196763 | 1 MΩ 1% 0603 | 3 | R108、R110、R111 |
| C106235 | 1 kΩ 1% 0402 | 2 | R401、R402 |
| C2909307 | 1.2 kΩ 1% 0402 | 1 | R400 |
| C60474 | 100 nF 16 V X7R 0402 | 7 | C100、C105、C200、C203、C204、C206、C400 |
| C5137560 | 2.2 µF 6.3 V 0603 | 1 | C101 |
| C1592 | 1 µF 16 V 0603 | 4 | C102、C103、C104、C202 |
| C46635918 | 4.7 µF 10 V 0402；核对偏压，必要时换参考 0603 | 1 | C205 |
| C46614473 | 100 pF C0G 0402 | 1 | C201 |
| C45359894 | 12 pF C0G 0402 | 6 | C210～C215 |
| DNP／待调 | 天线并联匹配 0402 | 0（留 2 位） | C217、C218 |

**明确不直接替换：** C411950 的 10 µH 电感、C52109822 的 3.0 nH 电感、C48986284 的 0.7 pF 电容分别不能直接视为这里的 10 µH 电源电感、3.9 nH RF 电感、0.8 pF RF 电容。0.7 pF 与 1.5 pF 库存留作天线调谐。

## 10. 转绘及首次调试顺序

1. 先按引脚表建原理图，核对 LED、USB、两段开关、Q100 源漏、陶瓷天线 NC 和 QFN 中心地焊盘。跑 EDA ERC；本文件不是已通过 ERC 的工程文件。
2. 锁定实际电池保护方式；复核 C205/C202 的有效容量、最终晶体订购参数以及新增射频物料。匹配值 TBD 不妨碍先画预留网络，但不能据此保证射频性能。
3. 先不接电池，用限流 5 V 检查 VBUS→VSYS→VDD，确认 VDD 不超过 3.6 V；再分别验证电池供电、USB 插拔和充电电流／终止。充电和系统供电是两个支路。
4. SWD 识别芯片、验证 LF/HF 时钟和半按／全按触点。先关闭 RGB 测休眠电流，再逐色测电流与导光效果；确认 DC/DC 装配配置与固件一致。
5. 布局完成后，按实际叠层处理 RF 50 Ω、复制芯片参考局部布局、按天线手册落实净空；装壳后做频偏、匹配与通信距离验证。

本版覆盖硬件接口，不包含 Canon BR-E1 配对／BLE 指令实现；硬件具备 BLE 能力不等于已验证与相机兼容。资料来源和已归档手册见 [reference/electrical/README.md](../../reference/electrical/README.md)。

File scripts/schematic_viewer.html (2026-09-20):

nRFCANON REMOTEGuruGuru-SEU / 电气设计

# 电路原理图 / v0.1

7 页矢量图纸 · 逐器件标注 JLC 物料编号 · 含引脚与 PCB layout 注释

设计审阅稿2026.09.20

## SCHEMATIC SHEETS

{{REFS}}定位

完整设计说明 ↗采购状态与完整 BOM ↗绘图源代码 ↗ (https://github.com/GuruGuru-SEU/nrf-canon-remote/tree/main/scripts)

依据当前文字原理图绘制。已核对绘图连接与 BOM；尚未完成 EDA ERC、射频调试或样机验证。

01 / USB-C 输入与电池充电

−100%＋适合宽度全屏下载 SVG ↗

{{DRAWINGS}}

JLC C… 可在嘉立创EDA搜索 · 未定编号另行注明 · DNP 为不装放大后可横向滚动查看

本页连接与 layout 注释

← 上一页下一页 →

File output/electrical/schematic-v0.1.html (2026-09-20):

跳至正文

nRFCANON REMOTEGuruGuru-SEU / 电气设计

文档目录 v0.1

查看目录

查看 Markdown 源文件 ↗ (https://github.com/GuruGuru-SEU/nrf-canon-remote/blob/main/output/electrical/%E5%8E%9F%E7%90%86%E5%9B%BE-v0.1.md)

设计草案版本 v0.1用于团队审阅

# nRF52832 Canon 遥控器：文字原理图 v0.1

更新日期：2026-09-20。用于转绘原理图和开始 PCB 规划；遥控器本板尚未完成 EDA ERC、PCB layout、射频调试或样机验证。

查看 7 页图形原理图：含元件符号、引脚编号、数值和 layout 注释，与本文同步更新。BAT54H 厂商脚号为 2=阳极、1=阴极。

2026-09-19：图纸已逐器件补充 JLC C… 物料编号，未确定编号的器件、DNP 位置与自带焊盘也分别标注。编号及采购状态见 完整 BOM。

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

## 1. 总体结构与电源网络

电源与功能框图

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

USB 口用于供电和充电。该 6Pin 接口没有 USB 数据线；nRF52832 也没有原生 USB 控制器。

## 2. USB-C、充电与供电切换

### 2.1 J100：HX TYPE-C 6P QTWT

采用自购的 6Pin 全贴母座，对应 C18357553。厂家图纸 (https://github.com/GuruGuru-SEU/nrf-canon-remote/blob/main/reference/component-models/C18357553.pdf)与库封装一起复核，不使用之前 16Pin 型号的焊盘编号。

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

### 2.2 U100：MSTP4054-42，SOT23-5L

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

该手册“功能描述”写充电终止为设定电流的 15%，另一段又写 PROG 低于 100 mV；两处不完全一致。首版按 100 mA 恒流设计，实际终止电流须实测，不承诺固定 10 mA 或 15 mA。CHG_N=0 表示正在充电；高电平也可能是没有 USB、未接电池或停充，须联合 USB_PRESENT_N 判断，不能单凭它显示“电池已充满”。依据：MSTP4054-42 手册第 3～7 页 (https://github.com/GuruGuru-SEU/nrf-canon-remote/blob/main/reference/electrical/MSTP4054-42.pdf)。

电池接口 J101： 两个焊线焊盘 1=VBAT(P+)、2=GND(P−)，旁边印 + / −，优先软线连接以节省高度。必须使用 1S、4.2 V 充电、带过充／过放／短路保护的软包电池。当前 LP402535 只是尺寸／容量候选，尚未确认购买版本是否带保护。若买裸电芯，必须增加保护电路后再使用本图的 J101。MSTP4054 本身不是电芯保护板，也没有电池 NTC 输入。

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

### 2.3 USB／电池自动切换

D100  BAT54H，Nexperia，SOD123F，新增：
      2/A/阳极 = VBUS_5V
      1/K/阴极 = VSYS（器件标记条一侧）

Q100  AO3401A，P-MOS，SOT23，新增：
      1/G = BAT_PATH_GATE
      2/S = VSYS
      3/D = VBAT

R102  0Ω 0402  : VBUS_5V — BAT_PATH_GATE        [C2906858]
R103  10k 0402 : BAT_PATH_GATE — GND            [C2906861]

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

Layout 注释： D100、Q100 与 LDO 输入放在一起。VBAT 充电支路和系统支路在电池接口附近分开；不要让系统大电流从充电芯片 BAT 引脚焊盘上绕行。Q100 栅极不悬空，R103 靠近栅极。

### 2.4 U101：ME6211C33M5G-N，3.3 V LDO

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

待机取舍： ME6211 首页标 40 µA 典型，C33 电气表标 60 µA 典型，首版功耗预算按较高的 60 µA。仅这一项已使 320 mAh 电池的理想时间约为 222 天，尚未扣除其他负载、自放电和不可用容量；不能据此宣称多年续航。若目标是很长的闲置时间，下一版优先换低静态电流 LDO。ME6211 手册，第 4、8 页 (https://github.com/GuruGuru-SEU/nrf-canon-remote/blob/main/reference/electrical/ME6211.pdf)。

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

### 2.5 USB 检测与电池测量

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

## 3. nRF52832 主控最小系统

U200 使用 nRF52832-QFAA。以下接线以 Nordic QFAx 参考设计 v1.1 为基础；原版 参考原理图 (https://github.com/GuruGuru-SEU/nrf-canon-remote/blob/main/reference/electrical/nrf52832_qfaa_dcdc_schematic.pdf)和 参考 PCB (https://github.com/GuruGuru-SEU/nrf-canon-remote/blob/main/reference/electrical/nrf52832_qfaa_dcdc_pcb.pdf)已归档。电源和 RF 区尽量保留其相对布局。

### 3.1 电源、内部稳压及复位

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

U200.31/VSS = GND
U200.45/VSS = GND
U200.EP     = GND     裸露中心焊盘必须接地，不得悬空

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

U200.24/P0.21/nRESET = RESET_N
R200 10k 0402 : VDD — RESET_N [C2906861]
TP205 = RESET_N，单独测试焊盘

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

Layout 注释：

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

### 3.2 32 MHz 与 32.768 kHz 时钟

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

C210 12pF C0G 0402 : XC1 — GND [C45359894]
C211 12pF C0G 0402 : XC2 — GND [C45359894]

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

C212 12pF C0G 0402 : XL1 — GND [C45359894]
C213 12pF C0G 0402 : XL2 — GND [C45359894]

两组晶振各有两颗负载电容，每个晶振端各接一颗 12 pF 到地，全部使用库存 C45359894。用值依据是用户已有开发板的反馈；原有的额外负载电容已删除。

晶体的标称 CL 保持原型号参数，外接电容值为每侧 12 pF，两者含义不同。遥控器 PCB 的起振与频偏在本板验证。参考：Nordic 时钟规格 (https://docs.nordicsemi.com/r/bundle/ps_nrf52832/page/clock.html)、X200 手册 (https://github.com/GuruGuru-SEU/nrf-canon-remote/blob/main/reference/electrical/YE32MDBCD2X.pdf)、X201 手册 (https://github.com/GuruGuru-SEU/nrf-canon-remote/blob/main/reference/electrical/KFC3276812520T.pdf)。

本次位号调整如下（“旧位号”指 2026-09-19 图纸）：

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

旧 C211、C213、C215、C217 四个额外负载电容位置删除。C300～C308 已随按键直连修改删除；RGB 电路电容保留分组编号 C400。

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

## 4. 按键

全部采用独立 GPIO 输入，低电平有效，使用 MCU 内部上拉；可配置低电平 GPIO SENSE 唤醒。没有矩阵扫描，中心两段可以独立检测。

每路通用接法如下，GPIO 与触点属于同一个 KEY_* 网络：

U200.GPIO（输入，开启内部上拉）── KEY_* ── 开关触点 ── GND

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

按 HRO 图纸 (https://github.com/GuruGuru-SEU/nrf-canon-remote/blob/main/output/review/k2-1831sl-datasheet.pdf) 的 a/b/c 标识建符号；若库符号使用数字脚号，须明确填写数字与字母对应，不按普通四脚轻触的“两两短接”方式猜测。预计半按第一段闭合、全按两段闭合；用实物通断测试确认时序后再确定固件事件处理。板上 a/b 的方向以厂家焊盘视图为准，注意与顶视图的镜像关系。

Layout 注释： 开关首先服从键帽顶柱和中心开关定位孔的机械位置。按键走线尽量短，与 RF 馈线、晶体和 DCC 保持距离，并保证连续地参考。不要让开关回地跨过晶体或 RF 的局部接地区。按键持续按住时内部上拉会耗电，休眠策略需处理被压住的按键。

## 5. RGB LED：NH-B1515RGBA-GF

D400 选库存 C52212029。厂家引脚为 2 共阳、1 红阴极、3 蓝阴极、4 绿阴极，不是按 R/G/B 顺序依次编号。引脚依据：手册第 6 页 (https://github.com/GuruGuru-SEU/nrf-canon-remote/blob/main/reference/electrical/NH-B1515RGBA-GF.pdf)。

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

D400.2/共阳 = VDD
C400 100nF 16V 0402 : VDD — GND [C60474]

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

电流估算式为 I≈(VDD−Vf−VOL)/R。VDD=3.3 V、先忽略 VOL，采用手册 R/G/B 典型 Vf=2.0/2.7/2.8 V 粗估，约为 1.1/0.6/0.5 mA。这些 Vf 分别是在 8/5/3 mA 下测得，并非本电路低电流时的保证值；实际电流、混色和导光后亮度须实测。电阻限流不提供恒流，电池低压导致 VDD 下降时，尤其绿／蓝通道可能明显变暗甚至不满足可见亮度。LED 电气表：手册第 3 页 (https://github.com/GuruGuru-SEU/nrf-canon-remote/blob/main/reference/electrical/NH-B1515RGBA-GF.pdf)。

充电指示仍由 MCU 读取 CHG_N 与 USB_PRESENT_N 后控制 RGB；该接法不提供 MCU 断电时的独立充电指示。

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

## 6. RF 与陶瓷天线

ANT200 使用库存 KH-2012-HM1 / C2925419。厂商定义 pin 1=INPUT，pin 2=NC；第二焊盘仅按图纸机械焊接，不接地、不连接到其他网络。

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

ANT200.2 = NC

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

分清两个网络： C216/L220 是 Nordic QFN48 的参考射频网络，本版先保留参考初值；C217/R221/C218 才是陶瓷天线的匹配预留，按你的要求暂不计算。厂商天线示例板为 90 × 50 mm，不能把它的 1.5 pF／0.7 pF 数值当作本遥控器最终匹配；库存这两种值可留作调试备料。Nordic 参考电路 (https://docs.nordicsemi.com/r/bundle/ps_nrf52832/page/ref_circuitry.html)、天线手册第 2～3 页 (https://github.com/GuruGuru-SEU/nrf-canon-remote/blob/main/reference/electrical/KH-2012-HM1.pdf)。

Layout 注释：

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

## 7. J200：4Pin SWD

单排 1×4，2.54 mm，固定顺序如下：

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

## 8. U200 完整引脚分配表

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

## 9. 首版 BOM 与库存对应

按所属电路、具体作用和已有／待采购状态拆分的完整表格见 完整电气 BOM v0.1。下面保留按料号合并的单板用量汇总。

下表数量是单板默认装配数，晶体负载电容共四颗，不含 DNP 和测试焊盘。原始订单是购入记录，实际剩余库存仍以实物为准。

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

## 10. 转绘及首次调试顺序

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

本版覆盖硬件接口，不包含 Canon BR-E1 配对／BLE 指令实现；硬件具备 BLE 能力不等于已验证与相机兼容。资料来源和已归档手册见 reference/electrical/README.md (https://github.com/GuruGuru-SEU/nrf-canon-remote/blob/main/reference/electrical/README.md)。

nRF Canon Remote · 电气设计 v0.1

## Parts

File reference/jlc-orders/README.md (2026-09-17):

# 本地订单与公开物料信息

原始立创订单导出包含收货地址、电话号码等个人信息，仅保留在本地，并通过 `.gitignore` 排除。运行建模与预览脚本不需要这些订单文件。

本工程使用或参考的物料：

| 用途 | 型号 | 采购来源 / 对应立创物料号 | 本版数量 |
| --- | --- | --- | --- |
| 中心两段开关 | K2-1831SL-A4SW-01 | 手工物料记录 | 1 |
| 圆环与下排开关 | TS-1101-C-W | C318938 | 7 |
| USB-C 母座 | hanxia（韩下）HX TYPE-C 6P QTWT，6Pin 全贴、四脚贴片 | 淘宝自购；对应立创 [C18357553](https://item.szlcsc.com/19545723.html) | 1 |
| RGB LED | NH-B1515RGBA-GF | C52212029 | 1 |
| 主控占位 | nRF52832 QFN48 | 另行选购 | 1 |
| 电池候选 | EEMB LP402535 / 320 mAh | 另行选购 | 1 |

USB-C 来自用户在淘宝单独购买，不在本地立创订单中。C18357553 仅用于查找同型号的数据手册、封装及 3D 模型，不代表采购来源。订单中的 SHOU HAN TYPE-C 16P QTWT（C5187472）不作为本工程选用件。

[another-one.txt](another-one.txt) 保留手工补充物料记录。尺寸依据、占位假设及机械验证范围见 [设计说明](../../output/设计说明.md)。

USB-C、TS-1101-C-W 与 RGB 的嘉立创 3D 模型已归档，详见 [器件模型来源与处理](../component-models/README.md)。

电气 v0.1 的完整库存对应、单板数量和新增物料见 [文字原理图 BOM](../../output/electrical/原理图-v0.1.md#9-首版-bom-与库存对应)。首版优先使用订单中的 MSTP4054-42、ME6211C33M5G-N、SI2302、KH-2012-HM1、两种晶体及阻容；新增的 AO3401A、BAT54H、合适的 10 µH 电感与 RF 参考网络器件属于设计选型，尚不代表已采购。库存 SCL1608S100KSP 的额定电流不足，不用于 MCU DC/DC。

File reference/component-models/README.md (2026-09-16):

# 嘉立创器件 3D 模型

下载日期：2026-09-17。OBJ 为嘉立创公开器件库返回的原始三角网格，单位 mm；JSON 为该物料关联的符号、封装和模型信息。`sources.json` 记录模型 UUID、下载地址及 SHA-256。模型与图纸的权利归各原作者所有。

| 器件 | 来源 | 本工程处理 |
| --- | --- | --- |
| HX TYPE-C 6P QTWT | [C18357553](https://item.szlcsc.com/19545723.html)；模型 `484957ac7c074e9c8fe12519331501ab` | 原始 3D 网格、材质与 10 个贴片焊盘；用户实际在淘宝购买 |
| TS-1101-C-W | [C318938](https://item.szlcsc.com/300030.html)；模型 `d40d76ae324c41b0b1b57d4fd0c55e23` | 七个开关均使用库模型；按源模型分离柱头和固定组件 |
| NH-B1515RGBA-GF | [C52212029](https://www.lcsc.com/product-detail/C52212029.html)；模型 `5a890419e9624fa093ef4d1a9cfb6526` | 预览使用库网格；高度 1.02 mm；干涉检查和 3MF 用完整外包络 |
| K2-1831SL-A4SW-01 | [韩荣厂家系列图纸](https://www.krhro.com/Product-Details/142.html) | 未取得该完整型号的嘉立创 3D 模型，仍为图纸建模，不标成下载模型 |
| nRF52832 / 电池 | Nordic 封装 / EEMB 外形资料 | 仍为尺寸包络 |

建模过程只平移、旋转下载网格，没有拉伸或重绘。USB 源模型 Y=-3.4 是插口前端，Z=-0.1 是最低焊脚；将焊脚底面放在 PCB 顶面。TS-1101-C-W 源模型的最低焊脚为 Z=-0.593335，安放后总高约 2.497716 mm，与标称 2.5 mm 对应。变换和源包络均写入 `output/review/geometry-checks.json`。

USB 库模型的焊耳总宽为 11.44 mm，而随附 HX 厂家图纸为 11.80 mm。预览保留下载网格，额外以放宽至 11.80 mm 的包络检查 PCB 和壳体；焊盘按同物料的库封装展示。全部 10 个焊盘距板边至少约 0.407 mm。库模型及库封装不能代替实物复核或正式 PCB 封装审核。

源 USB 和普通开关包含多个封闭实体；碰撞检查对每个器件内部实体先求并集，避免内部重叠被重复计数。RGB 源网格存在非封闭和重合面，因此只在预览中保留原网格，几何检查、剖面及 3MF 用保守外包络。打印件均单独检查为封闭、连通实体。`usb_shell.stl` 保留旧文件名，但现在包含整只 6Pin 母座的实体并集。

正常重建完全离线使用这些已归档的模型。校验或恢复缺失文件：

```sh
uv run python scripts/fetch_component_models.py
```

脚本只恢复缺失文件；下载内容必须与锁定的 SHA-256 一致。如果上游改变文件，脚本报错，不会静默更新模型。

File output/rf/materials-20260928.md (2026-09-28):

# 三种 JLC 板材 · 最终 Gerber 天线计算

**2026-09-28。** 本报告使用用户提供的三份 JLC 材料 PDF 和最终 Gerber，按材料分别建立 2.4 GHz 开放边界模型。NY2140 的 PDF 是 MSDS，不含 Dk/Df，因此额外引用制造商官方 1 GHz 表格，并按两种树脂含量分别计算。三份 PDF 对应四个条件工况。

> 结论先说：板材变化会改变天线输入阻抗，装入外壳后变化更大。匹配网络必须保留调试位；下面的 L/π 扫描是理想元件的起始候选，不是最终 BOM。

## 材料参数与来源

| 材料 | 本次仿真参数 | 处理状态 | PDF / 来源 |
|---|---|---|---|
| 上海南亚 NY2140 | RC55: Dk 4.15 / Df 0.0166；RC70: Dk 3.70 / Df 0.0178 | 1 GHz 两种树脂含量条件值 | [NY2140-MSDS.pdf](https://github.com/GuruGuru-SEU/nrf-canon-remote/blob/main/reference/rf/materials/NY2140-MSDS.pdf) |
| 台湾南亚 NP-140F | Dk 4.10 / Df 0.0130 | 1 GHz 典型范围中点 | [NP-140F.pdf](https://github.com/GuruGuru-SEU/nrf-canon-remote/blob/main/reference/rf/materials/NP-140F.pdf) |
| 航宇 HY-8101 | Dk 4.30 / Df 0.0220 | 表中典型值，频率未明确 | [HY-8101.pdf](https://github.com/GuruGuru-SEU/nrf-canon-remote/blob/main/reference/rf/materials/HY-8101.pdf) |

- **NP-140F**：PDF 第 1 页给出 1 GHz 典型 Dk 4.0–4.2、Df 0.012–0.014；本次取中点 Dk 4.10 / Df 0.0130，并保持到 2.4 GHz。这是频率外推，不是厂家 2.4 GHz 实测值。
- **HY-8101**：PDF 第 1 页给出典型 Dk 4.3、Df 0.022，但没有明确测试频率；第 2 页曲线只覆盖低频范围。本次按 Dk 4.30 / Df 0.0220 作为 2.4 GHz 近似。
- **NY2140**：用户 PDF 只有 MSDS；制造商 [NY2140/NY2140P 官方表格](https://www.nouyatec.com/product/base-material/lead-free-compatible/12)在 1 GHz 给出 R/C 55% 为 Dk 4.15 / Df 0.0166、R/C 70% 为 Dk 3.70 / Df 0.0178。本次把两种构造都算了；实际 JLC 订单的玻纤布、树脂含量和叠层仍需向板厂确认。

Dk 在模型中不随频率变化；损耗按 2.45 GHz 的 `σ = 2πf ε0 Dk·Df` 转成固定电导率输入 openEMS，因此等效 Df 在扫频中按 1/f 变化，BLE 频段内相对所填 Df 约偏差 −1.2% 到 +2.0%。这不是材料真实频散模型。Gerber 不包含板材牌号和频散数据。三份原始 PDF 已保存到仓库的 `reference/rf/materials/`。

## 仿真设置

- 几何：最终 Gerber `Gerber_nRF52832遥控器_2026-09-24.zip` 提取的全板双面铜、板框、PTH/NPTH；天线和馈线来自最终铜层。
- 板厚：用户确认 **1.6 mm**；铜面中心近似间距 1.545 mm。射频区域 XY 网格 0.10 mm，频率 2.2–2.7 GHz，重点观察 2.402–2.480 GHz BLE 频段。
- 参考面：L220 天线侧焊盘，50 Ω 集总端口；不是 nRF52832 的 ANT 引脚。
- `bare` 为裸板，`housed` 加入当前外壳 STL（假设 εr 2.8、tanδ 0.01）和软包电池金属包络。按键、USB-C、螺钉、人体及完整器件寄生未加入。
- 每个工况都实际执行 openEMS 时域求解，并检查 `-40 dB` 能量停止、端口数据有限、阻抗实部为正，以及 S1P 与 CSV 一致。

## 裸板结果

| 材料工况 | 2.441 GHz 输入阻抗 | 未匹配频段最差 S11 | 该工况 C-L-C π 候选（P1 / Zs / P2） | 匹配后最差 S11 |
|---|---:|---:|---|---:|
| NP-140F | 11.52 + j32.81 Ω | -2.24 dB | C 1.1 pF / L 4.3 nH / C 2.7 pF | -8.77 dB |
| HY-8101 | 11.94 + j39.40 Ω | -2.07 dB | C 0.6 pF / L 5.1 nH / C 2.2 pF | -9.03 dB |
| NY2140 / RC55% | 11.77 + j34.52 Ω | -2.22 dB | C 1.3 pF / L 4.3 nH / C 2.7 pF | -9.13 dB |
| NY2140 / RC70% | 14.36 + j18.52 Ω | -3.49 dB | C 3 pF / L 2.2 nH / C 5.1 pF | -11.10 dB |

## 装壳结果

| 材料工况 | 2.441 GHz 输入阻抗 | 未匹配频段最差 S11 | 该工况 C-L-C π 候选（P1 / Zs / P2） | 匹配后最差 S11 |
|---|---:|---:|---|---:|
| NP-140F | 10.30 + j91.41 Ω | -0.67 dB | C 0.3 pF / L 10 nH / C 1.1 pF | -6.06 dB |
| HY-8101 | 11.38 + j99.25 Ω | -0.69 dB | C 0.4 pF / L 12 nH / C 1 pF | -6.46 dB |
| NY2140 / RC55% | 10.81 + j93.47 Ω | -0.70 dB | C 0.5 pF / L 10 nH / C 1.1 pF | -6.19 dB |
| NY2140 / RC70% | 11.88 + j75.89 Ω | -0.98 dB | C 0.4 pF / L 8.2 nH / C 1.3 pF | -7.35 dB |

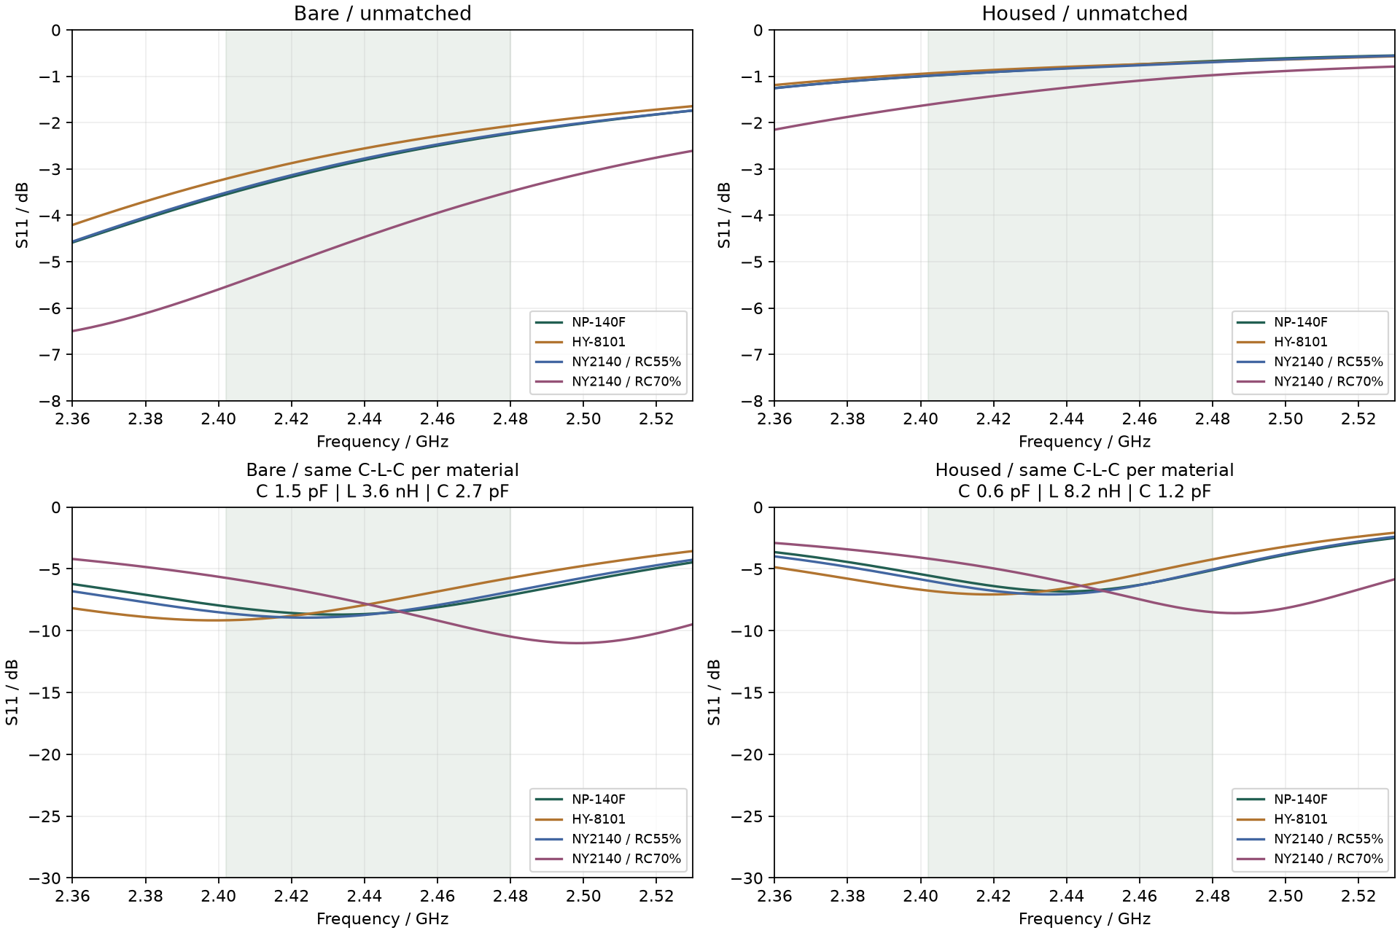
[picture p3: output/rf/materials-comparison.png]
四种材料工况的未匹配与共同 C-L-C 匹配结果


## 为什么专家说要看 L 型 / π 型

专家提醒补齐 **L 型 / π 型** 比较是有必要的。此前扫描也包含电感，但汇报只展示了选出的电容-电容候选，缺少含电感方案的对照；本次补齐了 LC 两元件和 π 三元件的各类组合。这里的 **L 型** 指一个串联支路加一个并联支路的拓扑：对本来呈感性的复数负载，两个电容也可能完成阻抗变换，但不能据此排除其他 LC 组合。

**π 型**有三个支路：输入侧并联 P1、串联 Zs、天线侧并联 P2。常见的低通形式是 **C-L-C**，但实际仍应由 VNA 和器件寄生决定。分支方向和元件位置见 [matching-topologies.svg](matching-topologies.svg)。

下表同时给出每种工况的含 L、C 两元件候选；`open` 表示该并联支路不装。以上和以下的“最佳”都只针对列明的有限离散值扫描，不代表全局最优。

| 材料 / 装配条件 | L 型候选（P1 / Zs / P2） | 匹配后频段最差 S11 |
|---|---|---:|
| NP-140F / 裸板 | open / L 2.7 nH / C 2.2 pF | -8.63 dB |
| NP-140F / 装壳 | open / L 9.1 nH / C 1.1 pF | -5.94 dB |
| HY-8101 / 裸板 | open / L 3.3 nH / C 2 pF | -8.81 dB |
| HY-8101 / 装壳 | open / L 10 nH / C 1 pF | -5.58 dB |
| NY2140 / RC55% / 裸板 | open / L 3 nH / C 2.2 pF | -9.04 dB |
| NY2140 / RC55% / 装壳 | open / L 8.2 nH / C 1.1 pF | -5.70 dB |
| NY2140 / RC70% / 裸板 | L 2.4 nH / C 1.5 pF / open | -9.09 dB |
| NY2140 / RC70% / 装壳 | open / L 6.8 nH / C 1.3 pF | -6.65 dB |

### 裸板共同候选

跨四个材料工况共同扫描的 **C-L-C π 网络**为 `C 1.5 pF / L 3.6 nH / C 2.7 pF`，最差频段 S11 为 **-5.72 dB**；同一拓扑在示例元件扰动中为 **-4.75 dB**（C：±max(5%, 0.05 pF)，L：±5%，27 种组合）。作为对照，包含电感的最佳混合 π 网络为 `C 1.5 pF / L 3.6 nH / C 2.7 pF`（-5.72 dB），包含电感的最佳 L 网络为 `open / L 1.8 nH / C 1.8 pF`（-5.43 dB）。

### 装壳共同候选

跨四个材料工况共同扫描的 **C-L-C π 网络**为 `C 0.6 pF / L 8.2 nH / C 1.2 pF`，最差频段 S11 为 **-4.16 dB**；同一拓扑在示例元件扰动中为 **-2.67 dB**（C：±max(5%, 0.05 pF)，L：±5%，27 种组合）。作为对照，包含电感的最佳混合 π 网络为 `C 1.8 pF / C 1.3 pF / L 27 nH`（-4.27 dB），包含电感的最佳 L 网络为 `L 6.8 nH / C 0.6 pF / open`（-3.83 dB）。

这些匹配值是在 0.2–22 pF、0.5–47 nH 离散理想元件网格上，以 2.402–2.480 GHz 的最差反射为目标扫描得到的。没有计入 Q、ESR、SRF、焊盘和走线寄生，因此不能直接把它们替换成 L220/C216/C217 的生产值。建议 PCB 保留 π 网络三个 0402 调试位，并在裸板和最终装配两种状态下以同一参考面用 VNA 复测。

π 网络的分支定义

## 限制与建议

1. 三份资料没有同时提供经过确认的 2.4 GHz、1.6 mm 成品叠层参数；因此材料之间的排序可以参考，绝对阻抗不能当成实测值。
2. NY2140 的 RC55/RC70 是制造商示例构造，不是本订单的保证上下界。拿到 JLC 实际 stackup 后，应以板厂叠层和玻纤布含量重算。
3. 外壳组只近似了壳体和电池，USB-C 外壳、按键、螺钉、焊盘寄生和人体耦合仍会改变匹配。
4. 先前 Dk=4.5 裸板模型在 0.15→0.10 mm 网格细化时，中心阻抗仍变化约 5.77%；本轮统一使用 0.10 mm，但没有完成每种材料的独立网格收敛，也没有装壳组的收敛研究。过孔为实心金属柱近似、PEC 铜面不计铜损、阻焊介质未建模。日志中未被网格使用的小图元仍是误差来源。
5. 在真实样机上先测裸板，再测最终外壳/电池装配；按 VNA 的频点和参考面调整 π 网络，最后再确认射频输出和 BLE 灵敏度。共同候选只优化了本次四个条件点，不能保证所有材料公差与批次都覆盖；本轮也没有计算辐射效率或通信距离。

## 数值检查

| 求解 | 停止时步数 | 停止能量 | 未使用图元警告数 |
|---|---:|---:|---:|
| np140f-bare | 44220 | -41.24 dB | 19 |
| np140f-housed | 58800 | -40.01 dB | 19 |
| hy8101-bare | 41808 | -41.30 dB | 19 |
| hy8101-housed | 48020 | -40.20 dB | 19 |
| ny2140-rc55-bare | 42880 | -40.98 dB | 19 |
| ny2140-rc55-housed | 53410 | -40.43 dB | 19 |
| ny2140-rc70-bare | 42880 | -40.47 dB | 19 |
| ny2140-rc70-housed | 49980 | -40.61 dB | 19 |

每组时域求解与阻抗换算已校验；匹配公式通过独立 ABCD 矩阵级联和已知阻抗变换核对。时域停止判据不等于空间网格收敛，也不等于实物验证。

## 下载与复算

- [材料对比与匹配数据 JSON](materials-matching.json)
- [材料对比图](materials-comparison.png) · [π/L 网络拓扑图](matching-topologies.svg)
- [八组 openEMS 求解证据](materials-solver-evidence.zip)
- [复算脚本](https://github.com/GuruGuru-SEU/nrf-canon-remote/tree/main/scripts/rf)：`simulate.py`、`match_networks.py`、`analyze_materials.py`

原始 Gerber SHA-256：`3fc97f87b7eec812915d751c0682821ee30cdcd28201358806b40dc6174ed5ac`。本次没有修改用户 PCB Layout。

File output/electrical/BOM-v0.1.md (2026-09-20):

# nRF52832 遥控器完整电气 BOM v0.1

整理日期：2026-09-20。对应 [文字原理图 v0.1](原理图-v0.1.md)，按单台用量统计。相同规格、相同作用的元件合并列出，所有装配位号均覆盖；同一料号用于不同电路时分行说明。

[查看图形原理图 v0.1](schematic-drawing-v0.1.html)，图中位号与本表一致。

图中每个器件旁均标注立创物料编号（`JLC C…`）或未分配编号的原因，可在嘉立创EDA中按编号搜索。2026-09-19 补核 U200、Q100、D100、L200 的供应商编号，采购状态仍为待采购；J100 为淘宝自购物料，对应编号仅用于查找同型号。S307 的立创编号尚未核实；L220、C216、J200 和电池尚待最终选型；DNP 位置及 PCB 自带焊盘没有采购编号。

“已有”指本地订单、补充物料记录或用户确认自购，实际剩余数量以实物为准。“待采购”指现有记录中没有合适选件。晶振负载按用户已有开发板反馈改为每侧一颗 12 pF，位号与原理图同步调整；射频数值仍为首版初值。

## USB-C 接口与静电保护

| 位号 | 型号／规格 | 单台数量 | 状态／物料号 | 所属部分 | 作用 |
| --- | --- | ---: | --- | --- | --- |
| J100 | HX TYPE-C 6P QTWT，6Pin 全贴 | 1 | 已有：淘宝自购，对应 C18357553 | USB 输入 | 引入 USB 5 V 电源，供电及充电 |
| R100、R101 | 5.1 kΩ，1%，0402 | 2 | 已有：C25905 | USB CC | 分别下拉 CC1、CC2，声明本设备为受电端 |
| C100 | 100 nF，16 V，X7R，0402 | 1 | 已有：C60474 | USB 输入 | 接口附近的高频旁路 |
| D101 | PESDNC2FD5VB，DFN1006-2 | 1 | 已有：C5356109 | USB ESD | VBUS 电源线静电保护 |
| D102 | PESDNC2FD5VB，DFN1006-2 | 1 | 已有：C5356109 | USB ESD | CC1 线静电保护 |
| D103 | PESDNC2FD5VB，DFN1006-2 | 1 | 已有：C5356109 | USB ESD | CC2 线静电保护 |

## 电池与充电

| 位号 | 型号／规格 | 单台数量 | 状态／物料号 | 所属部分 | 作用 |
| --- | --- | ---: | --- | --- | --- |
| 电池（接 J101） | 1S、4.2 V 充电、带保护软包；候选约 320 mAh | 1 | 待采购：最终型号待定 | 电池 | 储能供电；须包含过充／过放／短路保护 |
| U100 | MSTP4054-42，SOT23-5L | 1 | 已有：C49208527 | 充电 | 单节锂电池恒流／恒压充电 |
| C101 | 2.2 µF，6.3 V，0603 | 1 | 已有：C5137560 | 充电输入 | 充电器 VCC 输入去耦 |
| C102 | 1 µF，16 V，0603 | 1 | 已有：C1592 | 充电 BAT 端 | 电池端局部旁路与稳定 |
| R105 | 10 kΩ，1%，0402 | 1 | 已有：C2906861 | 充电电流设置 | PROG 到地，将充电电流设为约 100 mA |
| R106 | 10 kΩ，1%，0402 | 1 | 已有：C2906861 | 充电状态 | CHG_N 上拉至 VDD，供 MCU 读取 |

J101 为 PCB 自带的两个焊线焊盘，无需单独购买连接器；电池按带引线采购。若改用插拔连接器，连接器及线束需另列 BOM。

## 电源切换与 3.3 V 稳压

| 位号 | 型号／规格 | 单台数量 | 状态／物料号 | 所属部分 | 作用 |
| --- | --- | ---: | --- | --- | --- |
| Q100 | AOS AO3401A，P-MOS，SOT23 | 1 | 待采购：[C15127](https://www.lcsc.com/product-detail/MOSFET_Alpha-Omega-Semicon-AO3401A_C15127.html) | 电池供电通路 | 无 USB 时接通电池；USB 供电时关闭，阻止 VSYS 直接灌入电池 |
| D100 | Nexperia BAT54H,115，肖特基，SOD123F | 1 | 待采购：[C426769](https://www.lcsc.com/es/product-detail/Schottky-Barrier-Diodes-SBD_Nexperia_C426769.html) | USB 供电通路 | USB→VSYS 单向导通，阻止电池电源反灌 USB；2=A 接 VBUS，1=K 接 VSYS |
| R102 | 0 Ω，0402 | 1 | 已有：C2906858 | PMOS 控制 | 将 VBUS 接到 Q100 栅极，并保留可断开调试的位置 |
| R103 | 10 kΩ，1%，0402 | 1 | 已有：C2906861 | PMOS 控制 | 拔掉 USB 后拉低栅极，让电池通路导通 |
| U101 | ME6211C33M5G-N，3.3 V，SOT23-5 | 1 | 已有：C82942 | 系统稳压 | 将 VSYS 稳压为 MCU 与 RGB 使用的 VDD |
| C103 | 1 µF，16 V，0603 | 1 | 已有：C1592 | LDO 输入 | VIN 去耦 |
| C104 | 1 µF，16 V，0603 | 1 | 已有：C1592 | LDO 输出 | 输出稳定和瞬态供电 |
| R104 | 0 Ω，0402 | 1 | 已有：C2906858 | VDD 电源支路 | 连接 VREG_3V3 与 VDD，可串入电流表测 MCU 和 RGB 电流 |

## USB 检测与电池电压检测

| 位号 | 型号／规格 | 单台数量 | 状态／物料号 | 所属部分 | 作用 |
| --- | --- | ---: | --- | --- | --- |
| Q101 | SI2302，N-MOS，SOT23 | 1 | 已有：C2891732 | USB 检测 | 将 USB 5 V 是否存在转换为 VDD 电平的低有效信号 |
| R107 | 10 kΩ，1%，0402 | 1 | 已有：C2906861 | USB 检测 | Q101 栅极串阻，限制栅极充放电瞬态电流 |
| R108 | 1 MΩ，1%，0603 | 1 | 已有：C49196763 | USB 检测 | Q101 栅极下拉，防止悬空 |
| R109 | 10 kΩ，1%，0402 | 1 | 已有：C2906861 | USB 检测 | USB_PRESENT_N 上拉到 VDD |
| R110、R111 | 1 MΩ，1%，0603 | 2 | 已有：C49196763 | 电池 ADC | 构成 1/2 分压，将满电约 4.2 V 降到约 2.1 V |
| C105 | 100 nF，16 V，X7R，0402 | 1 | 已有：C60474 | 电池 ADC | 分压点滤波，并提供采样所需的瞬态电荷 |

## 主控、内部电源及复位

| 位号 | 型号／规格 | 单台数量 | 状态／物料号 | 所属部分 | 作用 |
| --- | --- | ---: | --- | --- | --- |
| U200 | nRF52832-QFAA（订购型号 NRF52832-QFAA-R），QFN48，6×6 mm | 1 | 待采购：[C77540](https://www.lcsc.com/product-detail/RF-Transceiver-ICs_NORDIC-NRF52832-QFAA-R_C77540.html) | 主控／BLE | 读取按键、控制 RGB、运行蓝牙协议与遥控逻辑 |
| C200 | 100 nF，16 V，X7R，0402 | 1 | 已有：C60474 | MCU DEC1 | 内部电源节点去耦 |
| C201 | 100 pF，25 V，C0G，0402 | 1 | 已有：C46614473 | MCU DEC3 | 按 Nordic 参考电路对 DEC3 高频去耦 |
| C202 | 1 µF，16 V，X5R，0603 | 1 | 已有：C1592，需核对替代条件 | MCU DEC4 | 内部稳压节点输出电容；参考 BOM 为 X7R |
| C203、C204、C206 | 100 nF，16 V，X7R，0402 | 3 | 已有：C60474 | MCU VDD | 分别靠近 pin 13、36、48，对电源作本地去耦 |
| C205 | 4.7 µF，10 V，±20%，0402 | 1 | 已有：C46635918，需核对替代条件 | MCU VDD | 电源储能；参考 BOM 为 0603／±10%，需核对偏压下有效容量 |
| L200 | MLZ1608M100WT000，10 µH，±20%，0603 | 1 | 待采购：[C76798](https://item.szlcsc.com/77925.html) | MCU DC/DC | 降压转换的储能电感；库存同感值电感额定电流不足 |
| L201 | SDCL1005C15NKTDF，15 nH，±10%，0402 | 1 | 已有：C370189 | MCU DC/DC | 串联高频滤波，配合 L200 使用 |
| R200 | 10 kΩ，1%，0402 | 1 | 已有：C2906861 | 复位 | RESET_N 上拉 |
| C214、C215 | 12 pF，C0G，0402 | 2 | 已有：C45359894 | MCU 杂散抑制 | P0.25/P0.26 到地，沿用 errata 138 的参考处理 |

## 时钟

| 位号 | 型号／规格 | 单台数量 | 状态／物料号 | 所属部分 | 作用 |
| --- | --- | ---: | --- | --- | --- |
| X200 | YE32MDBCD2X，32 MHz，CL=10 pF，2016-4P | 1 | 已有：C54427949 | 高频时钟 | 为射频与系统提供精确高频时钟基准 |
| C210、C211 | 12 pF，C0G，0402 | 2 | 已有：C45359894 | 高频晶体负载 | XC1、XC2 各一颗到地，采用已有开发板用值 |
| X201 | KFC3276812520T，32.768 kHz，CL=12.5 pF，3215-2P | 1 | 已有：C18209174 | 低频时钟 | 低功耗计时与 BLE 连接时序基准 |
| C212、C213 | 12 pF，C0G，0402 | 2 | 已有：C45359894 | 低频晶体负载 | XL1、XL2 各一颗到地，采用已有开发板用值 |

## 按键

| 位号 | 型号／规格 | 单台数量 | 状态／物料号 | 所属部分 | 作用 |
| --- | --- | ---: | --- | --- | --- |
| S300～S303 | TS-1101-C-W，SMT 轻触 | 4 | 已有：C318938 | 圆环按键 | 上、下、左、右四个方向输入 |
| S304～S306 | TS-1101-C-W，SMT 轻触 | 3 | 已有：C318938 | 下排圆键 | 三个独立功能键输入 |
| S307 | K2-1831SL-A4SW-01，两段轻触 | 1 | 已有：手工物料记录，JLC 编号未核实 | 中心按键 | 提供半按／全按两路触点 |

9 路触点直接连接对应 GPIO 与 GND，使用 MCU 内部上拉和固件去抖。R300～R308、C300～C308 已从设计删除；不计入装配或 DNP 位置。

## RGB 指示灯

| 位号 | 型号／规格 | 单台数量 | 状态／物料号 | 所属部分 | 作用 |
| --- | --- | ---: | --- | --- | --- |
| D400 | NH-B1515RGBA-GF，共阳 RGB | 1 | 已有：C52212029 | 状态指示 | 共阳接 VDD，GPIO 低有效驱动，显示配对、连接、电量和充电状态 |
| R400 | 1.2 kΩ，1%，0402 | 1 | 已有：C2909307 | 红灯限流 | 限制红色 LED 电流 |
| R401、R402 | 1 kΩ，1%，0402 | 2 | 已有：C106235 | 绿／蓝灯限流 | 分别限制绿色、蓝色 LED 电流 |
| C400 | 100 nF，16 V，X7R，0402 | 1 | 已有：C60474 | RGB 供电 | VDD 在 LED 附近的本地旁路 |

三路 GPIO 经 R400～R402 分别接 LED 阴极，使用 H0S1 高灌电流模式；共阳接 VDD（R104 后），不能接 VSYS。Q400～Q402、R403～R408 已删除，共减少 9 件已有物料，不保留 DNP。限流值沿用库存，亮度和低电量表现配合导光件实测；固件初始化及低有效 PWM 要求见文字原理图第 5 节。

## 射频与天线

| 位号 | 型号／规格 | 单台数量 | 状态／物料号 | 所属部分 | 作用 |
| --- | --- | ---: | --- | --- | --- |
| L220 | 3.9 nH，高 Q 射频电感，±5%，0402 | 1 | 待采购：完整型号待定 | 芯片端 RF 网络 | 与 C216 配合完成射频匹配和滤波 |
| C216 | 0.8 pF，C0G/NP0，±5%（或不差于此的绝对误差），0402 | 1 | 待采购：完整型号待定 | 芯片端 RF 网络 | ANT 侧对地电容，与 L220 配合 |
| R221 | 0 Ω，0402 | 1 | 已有：C2906858 | 天线匹配 | 首版串联连通位，调试时可换电感／电容或拆开测量 |
| ANT200 | KH-2012-HM1，陶瓷天线，2.0×1.2×0.5 mm | 1 | 已有：C2925419 | 蓝牙天线 | 收发 2.4 GHz 电磁波；pin 2 保持 NC |

## 调试接口

| 位号 | 型号／规格 | 单台数量 | 状态／物料号 | 所属部分 | 作用 |
| --- | --- | ---: | --- | --- | --- |
| J200 | 1×4，2.54 mm 排针 | 1 | 待采购（可不装、改用探针） | SWD | 下载和调试；1=VDD、2=GND、3=IO、4=CLK |

## 不装元件和 PCB 自带焊盘

这些位置保留在 PCB 上，但不计入上述单台装配数量。

| 位号 | 规格／数量 | 状态 | 所属部分 | 作用 |
| --- | --- | --- | --- | --- |
| C217、C218 | 0402，2 个位置 | DNP／待调，暂不采购 | 天线匹配 | 两个对地调谐臂，实板测量后确定值 |
| J101 | 正负焊线焊盘，共 2 个 | PCB 自带，无需采购 | 电池接口 | 接电池保护板 P+、P− 引线 |
| TP200～TP204 | 5 个测试焊盘 | PCB 自带，无需采购 | 电源测试 | 依次为 VDD、GND、VBUS、VBAT、VSYS |
| TP205 | 1 个测试焊盘 | PCB 自带，无需采购 | 复位调试 | RESET_N |
| TP206、TP207 | 2 个测试焊盘 | PCB 自带，无需采购 | 状态测试 | CHG_N、USB_PRESENT_N |

## 采购汇总与取舍

默认装配共 **65 件**（含 1 块外接电池和 1 个 SWD 排针），其中已有物料对应 **57 件**，待采购 **8 类、各 1 件**。不装排针时减 1 件；这不是独立料号种类数，也不含焊盘、PCB、外壳、螺丝和装配耗材。

| 待采购项 | 单台数量 | 备注 |
| --- | ---: | --- |
| nRF52832-QFAA | 1 | C77540；QFN48 主控 |
| AO3401A | 1 | C15127；P-MOS，库存 SI2302 为 N-MOS，不能替代 |
| Nexperia BAT54H | 1 | C426769；SOD123F 肖特基，库存 1N4148WS 不直接替代 |
| MLZ1608M100WT000 | 1 | C76798；10 µH 电源电感，库存 C411950 额定电流不足 |
| 3.9 nH 射频电感 | 1 | 库存 3.0 nH 不直接替代 |
| 0.8 pF C0G 电容 | 1 | 库存 0.7 pF 不直接替代；完整采购型号待锁定 |
| 带保护的单节软包电池 | 1 | 尺寸、容量、允许充电电流与保护方式一并确认 |
| 1×4、2.54 mm 排针 | 1 | 可不装并使用探针 |

- 已有 0.7 pF（C48986284）和 1.5 pF（C5448836）可作为天线调谐备料，但未分配默认装配位号，不额外计数。
- 12 pF（C45359894）共六颗：HF 两颗、LF 两颗、P0.25/P0.26 杂散抑制两颗。本版不再装配原晶振支路的 2.4 pF（C45359903）与 10 pF（C32949）。
- C202/C205 的参考规格差异已标明，后续验证若不满足再更新采购状态。
- 若选择内部 LDO 模式，可不装 L200/L201，并在固件中关闭 DC/DC；当前统计仍按默认装配两颗电感计算。
- 本表列出原理图使用的电气物料；电池保护以电池包集成为前提。若改成裸电芯，保护芯片和保护 MOS 等必须另行设计并加入 BOM。

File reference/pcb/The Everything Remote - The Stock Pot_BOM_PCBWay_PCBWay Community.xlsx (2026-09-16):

 |  |  | xxxx xxxx xxxxx xxPCS BOM (Sample Bill of Materials)
Item # | *Designator | *Qty | Manufacturer | *Mfg Part # | Description / Value | *Package/Footprint | Type | Your Instructions / Notes
1 | R1, R2 | 2 | YAGEO | MFR-25FTE52-10K | 10k | RESISTOR_AXIAL-10.16MM-PITCH
2 | U$1 | 1 |  |  | LOLIN32LITE_V2 | LOLIN32LITE_V2
3 | SW_0, SW_2, SW_4, SW_5, SW_12, SW_13, SW_14, SW_15, SW_16, SW_17, SW_18, SW_19, SW_22, SW_23, SW_25, SW_26, SW_27, SW_32, SW_33, SW_34, SW_35 | 21 | SparkFun Electronics | 00097 | Momentary Switch (Pushbutton) - SPST
4 | / | 1 |  |  | Lithium Polymer Battery - 1100mah
Need a quick and accurante quote? Need an efficient production? Please read SMT Ordering Necessary Files & Info in 1 minute. Thank you very much! (https://www.pcbway.com/smt_ordering_guide.html)
Click for Instructions on How to Create a BOM (https://www.pcbway.com/blog/PCB_Assembly/How_to_Build_a_BOM__Bill_Of_Materials_.html)

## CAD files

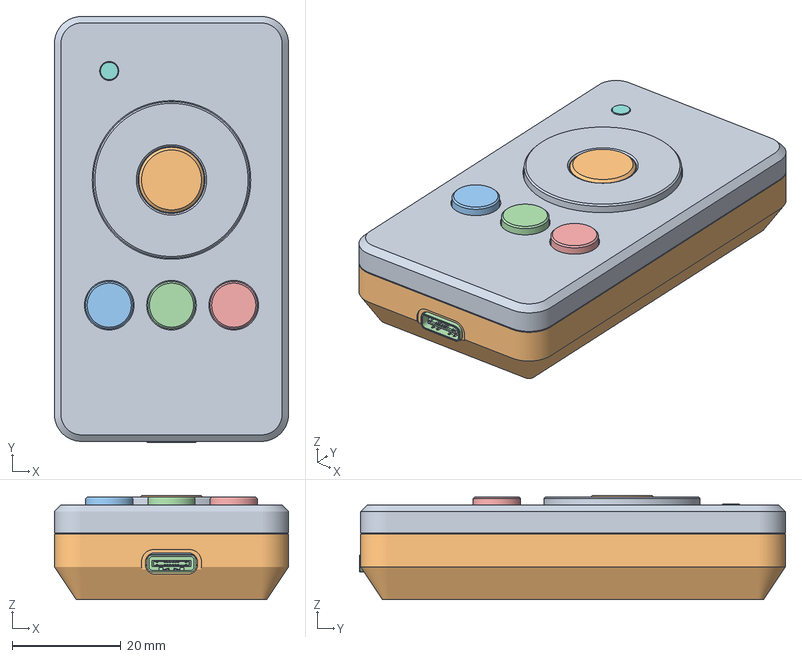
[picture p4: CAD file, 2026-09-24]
output/models/remote_assembly.3mf
43.0 x 78.2 x 19.1 mm
上盖 · 右上 / 下左右三点固定
下盖 · 顶角圆弧定位台 / 参考梯形收底
PCB · 73.42869999999999 × 36.76 × 1.60 mm
HX TYPE-C 6P QTWT · 嘉立创 C18357553 原始模型
USB-C 库焊盘 20
USB-C 库焊盘 18
USB-C 库焊盘 17
USB-C 库焊盘 19
USB-C 库焊盘 B12
USB-C 库焊盘 B9
USB-C 库焊盘 A5
USB-C 库焊盘 B5
USB-C 库焊盘 A9
USB-C 库焊盘 A12
NH-B1515RGBA-GF · 嘉立创模型 / 包络配合检查
导光柱 · Ø3.2 / 肩部 Ø4.5
四向圆环 · 一体顶柱
中心两段键 · 一体顶柱
下排圆键 1 · 一体顶柱
下排圆键 2 · 一体顶柱
下排圆键 3 · 一体顶柱
TS-1101-C-W · 嘉立创原始模型 x 7
key_ring_1 柱头
key_ring_2 柱头
key_ring_3 柱头
key_ring_4 柱头
K2-1831SL-A4SW-01 · 厂家图纸建模
key_center_1 柱头
key_circle1_1 柱头
key_circle2_1 柱头
key_circle3_1 柱头
nRF52832 · QFN48 包络
EEMB LP402535 · 320 mAh · 25.5 × 36 × 4.3
电池绝缘带（示意）

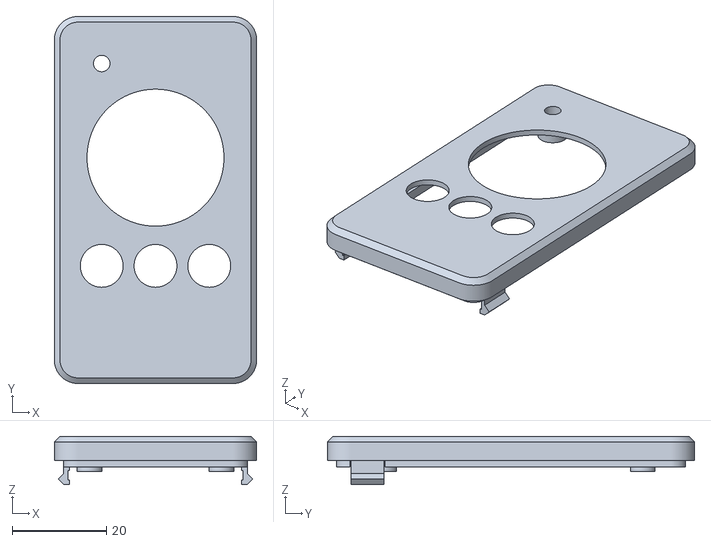
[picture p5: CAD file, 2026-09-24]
output/models/shell_top.stl
43.0 x 78.0 x 10.3

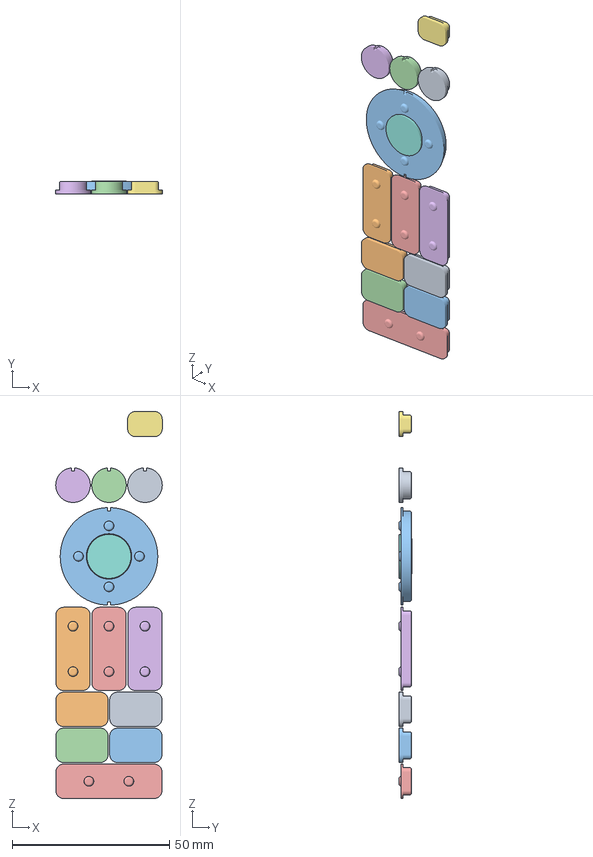
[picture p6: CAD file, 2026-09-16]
reference/enclosure/buttons_blank.3mf
33.9 x 4.20 x 123.0 mm
Back
Channel
Directional
Home
Mute / Settings
Play
Power
Select
Shortcut 1
Shortcut 2
Shortcut 3
Shortcut 4
Shortcut 5
Volume

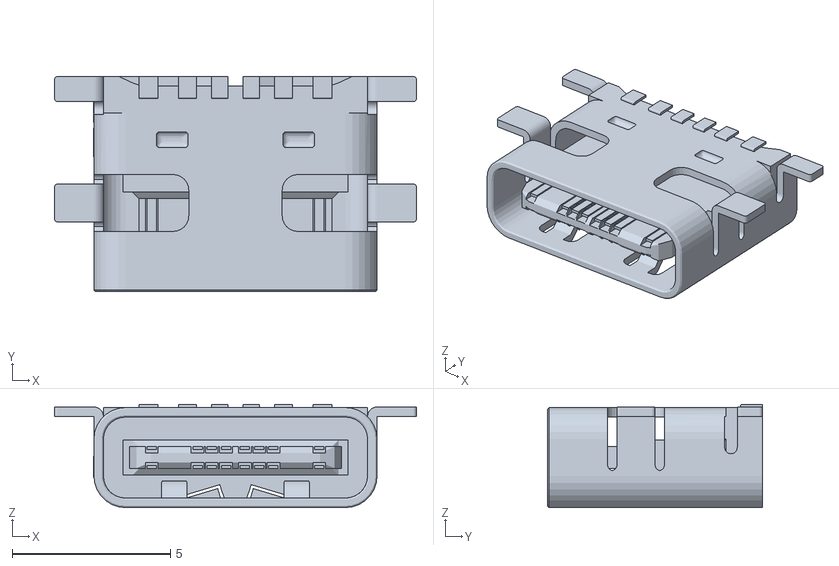
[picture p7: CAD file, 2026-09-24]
output/models/usb_shell.stl
11.4 x 6.80 x 3.26

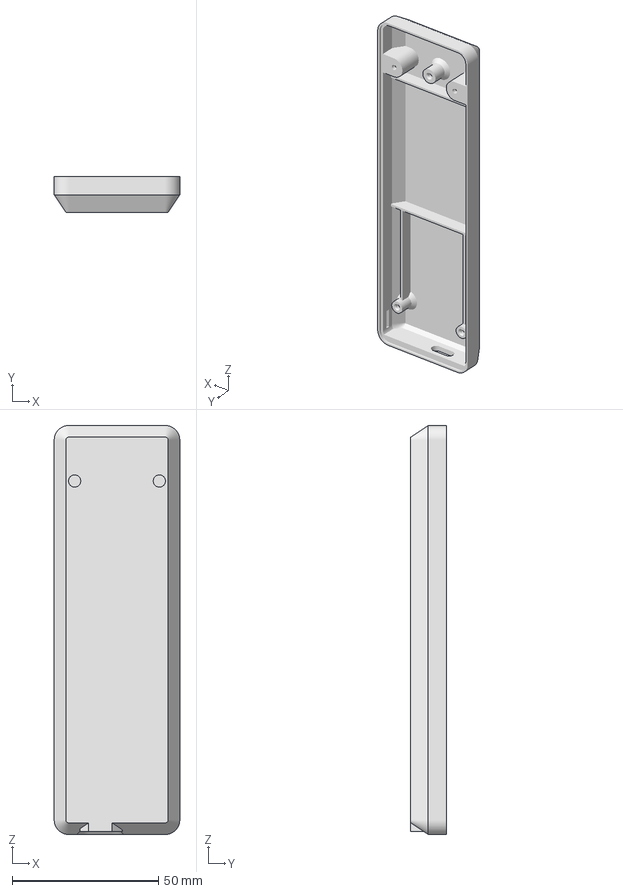
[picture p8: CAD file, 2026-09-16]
reference/enclosure/shell_bottom.3mf
43.0 x 12.3 x 140.0 mm

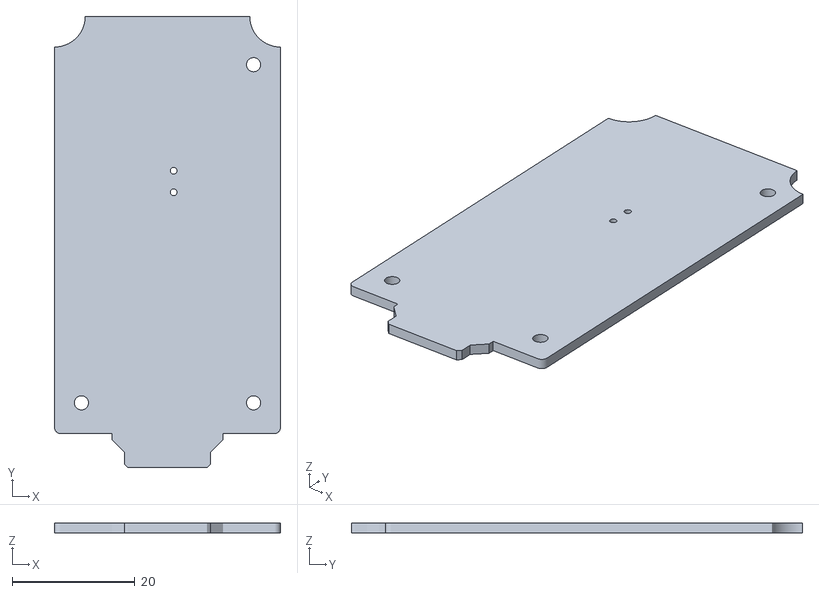
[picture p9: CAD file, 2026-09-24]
output/models/pcb.stl
36.8 x 73.4 x 1.60

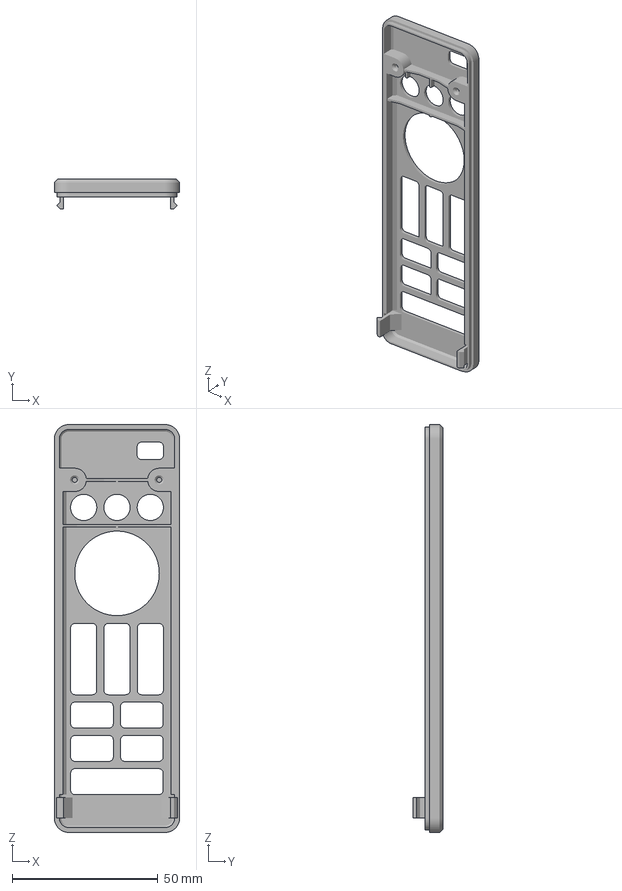
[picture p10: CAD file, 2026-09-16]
reference/enclosure/shell_top.3mf
43.0 x 10.3 x 140.0 mm

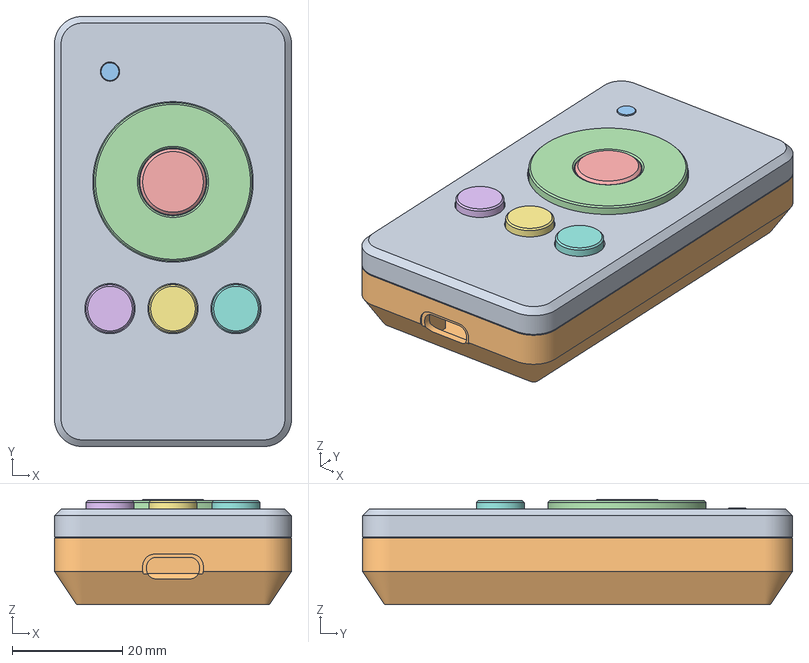
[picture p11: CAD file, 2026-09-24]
output/models/printable_parts.3mf
43.0 x 78.0 x 19.1 mm
上盖 · 右上 / 下左右三点固定
下盖 · 顶角圆弧定位台 / 参考梯形收底
导光柱 · Ø3.2 / 肩部 Ø4.5
四向圆环 · 一体顶柱
中心两段键 · 一体顶柱
下排圆键 1 · 一体顶柱
下排圆键 2 · 一体顶柱
下排圆键 3 · 一体顶柱

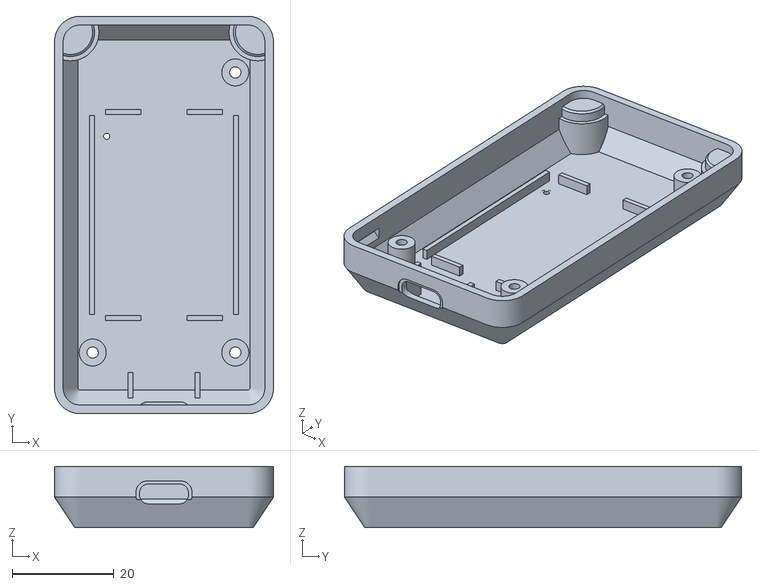
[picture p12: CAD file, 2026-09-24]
output/models/shell_bottom.stl
43.0 x 78.0 x 12.1

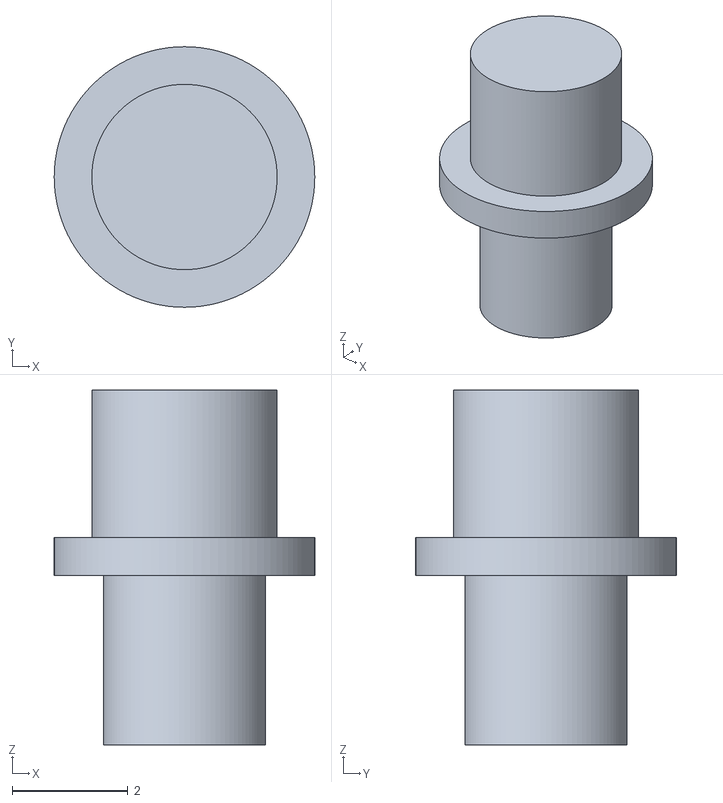
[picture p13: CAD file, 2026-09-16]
output/models/light_pipe.stl
4.50 x 4.50 x 6.13

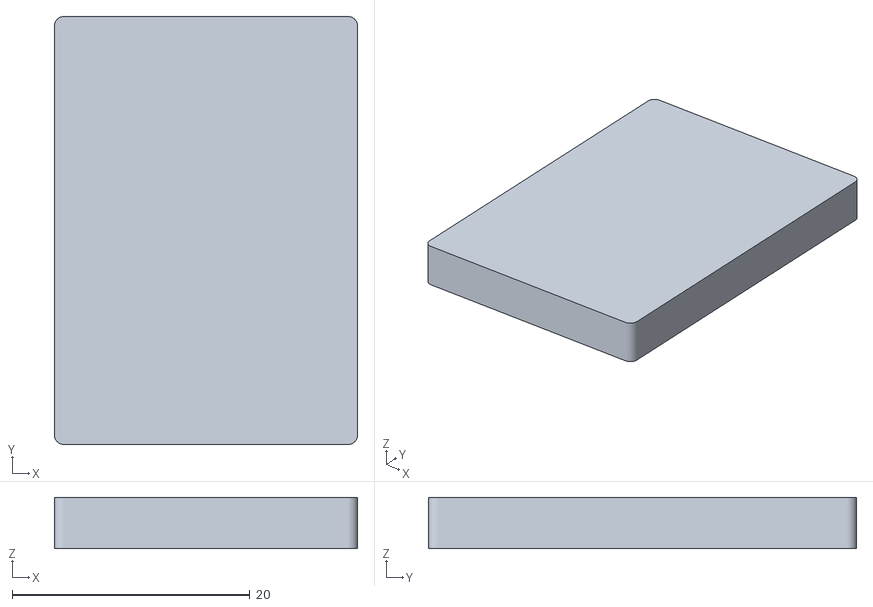
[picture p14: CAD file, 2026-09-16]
output/models/battery.stl
25.5 x 36.0 x 4.30

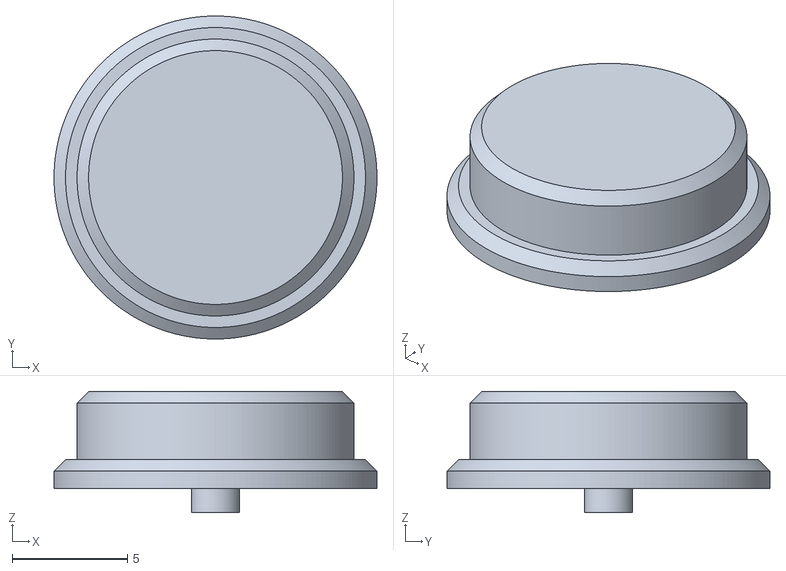
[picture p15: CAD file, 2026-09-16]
output/models/key_center.stl
14.0 x 14.0 x 5.25

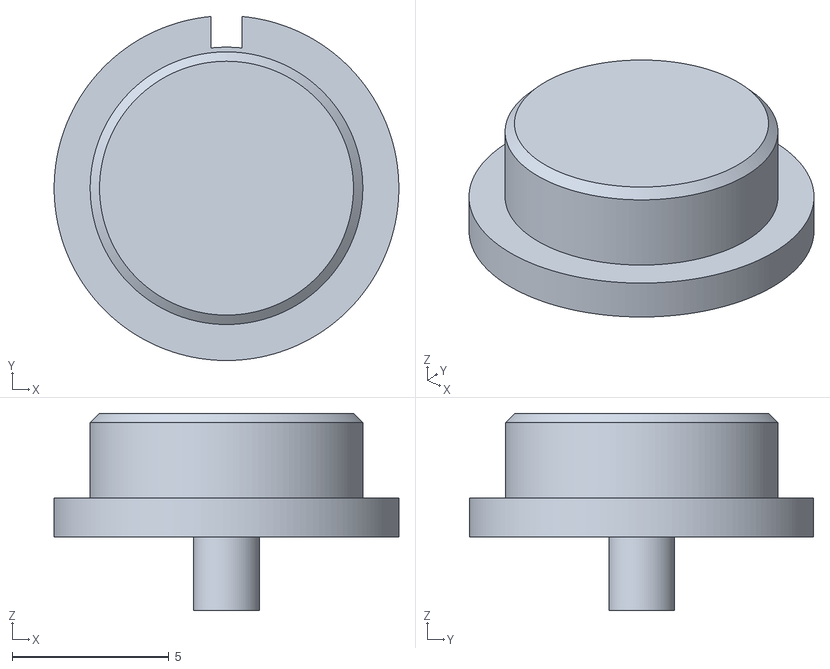
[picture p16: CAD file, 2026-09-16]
output/models/key_circle1.stl
11.0 x 11.0 x 6.30

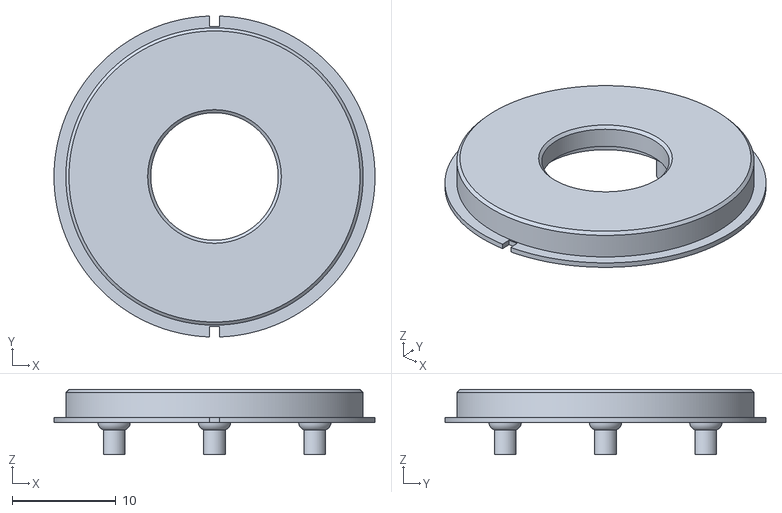
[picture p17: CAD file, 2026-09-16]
output/models/key_ring.stl
31.0 x 31.0 x 6.30

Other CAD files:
output/models/pcb_outline.dxf
output/models/key_circle2.stl
output/models/key_circle3.stl
reference/component-models/C318938.obj
reference/component-models/C18357553.obj
reference/component-models/C52212029.obj

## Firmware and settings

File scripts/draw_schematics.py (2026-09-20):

"""Draw the reviewed v0.1 circuit with Schemdraw; run with uv run.

Every physical terminal is registered against electrical_circuit.py. The
geometry audit checks that terminals actually touch their intended wires,
that wire islands have a net label/ground, and that different nets never
intersect. This is drawing QA, not an EDA ERC or a hardware qualification.
"""
from __future__ import annotations

import hashlib
import html
import json
from pathlib import Path
import re
import xml.etree.ElementTree as ET

import schemdraw
import schemdraw.elements as elm
from schemdraw.segments import Segment, SegmentText, SegmentPoly
from shapely.geometry import LineString, Point

from electrical_circuit import PARTS, MCU, KEYS

ROOT = Path(__file__).resolve().parents[1]
OUT = ROOT / 'output/electrical'
ASSETS = OUT / 'schematic-assets'
INK = '#203543'
WIRE = '#267365'
MUTED = '#687b83'
RULE = '#d5e1df'
AMBER = '#a47731'
SUPPLIER = '#4c718a'
FONT = 'Arial, PingFang SC, Microsoft YaHei, sans-serif'
SHEETS = []
DRAWN = {}


class Sheet:
    def __init__(self, number, slug, title, subtitle, notes, height=30):
        self.number, self.slug, self.title = number, slug, title
        self.notes, self.height = notes, height
        self.wires, self.ports, self.terminals, self.ncs = [], [], [], []
        self.supplier_labels = []
        self.d = schemdraw.Drawing(show=False, canvas='svg', inches_per_unit=.43,
                                  fontsize=11, font=FONT, color=INK, lw=1.35)
        self.box((.15, .15), (47.85, height-.15), color=RULE, fill='white', lw=.8)
        self.text(1.3, height-1.15, f'{number:02d} / 07', size=11, color=WIRE)
        self.text(5.0, height-1.2, title, size=21)
        self.text(46.6, height-1.1, 'nRF CANON REMOTE', size=11, align='right')
        self.text(46.6, height-1.9, 'SCHEMATIC v0.1  /  2026-09-20', size=9, color=MUTED, align='right')
        self.text(5.0, height-2.15, subtitle, size=10, color=MUTED)
        self.rule((1.3, height-2.9), (46.7, height-2.9))
        self.box((1.3, 1.65), (46.7, 6.35), color=RULE, fill='#f7faf9', lw=.7)
        self.text(2, 5.6, '连接与 LAYOUT', size=11, color=WIRE)
        for i, note in enumerate(notes):
            self.text(2, 4.65-i*.78, note, size=10, color=INK)
        self.text(1.3, .85, '同名网络跨页相连  ·  实心点为连接  ·  × 为 NC  ·  DNP 为不装  ·  JLC C… 为立创物料编号', size=9, color=MUTED)
        self.text(46.7, .85, f'设计审阅稿  /  {number:02d}', size=9, color=MUTED, align='right')
        SHEETS.append(self)

    def graphic(self, segments):
        obj = elm.Element()
        obj.segments.extend(segments)
        # Absolute page geometry must not inherit the last component's angle.
        self.d.add(obj.at((0, 0)).theta(0))

    def text(self, x, y, text, size=11, color=INK, align='left'):
        self.graphic([SegmentText((x, y), text, fontsize=size, font=FONT,
                                 color=color, align=(align, 'center'))])

    def rule(self, a, b, color=RULE, ls='-', lw=.8):
        self.graphic([Segment([a, b], color=color, lw=lw, ls=ls)])

    def box(self, a, b, color=INK, fill=None, lw=1.2, ls='-'):
        x1, y1 = a; x2, y2 = b
        self.graphic([SegmentPoly([(x1,y1),(x2,y1),(x2,y2),(x1,y2)],
                                  color=color, fill=fill, lw=lw, ls=ls, zorder=0)])

    def section(self, x, y, label):
        self.text(x, y, label, size=11, color=WIRE)

    def supplier(self, ref, x, y, align='left'):
        self.text(x, y, PARTS[ref]['supplier_label'], size=8.5,
                  color=SUPPLIER if PARTS[ref]['lcsc'] else MUTED, align=align)
        self.supplier_labels.append(dict(ref=ref, text=PARTS[ref]['supplier_label'], p=[x,y]))

    def wire(self, net, *points):
        assert net is not None
        for a, b in zip(points, points[1:]):
            if Point(a).distance(Point(b)) < 1e-7:
                continue
            assert abs(a[0]-b[0]) < 1e-6 or abs(a[1]-b[1]) < 1e-6, (a,b)
            self.d.add(elm.Line().at(a).to(b).color(WIRE).linewidth(1.2))
            self.wires.append(dict(net=net, a=list(a), b=list(b)))

    def dot(self, p):
        self.d.add(elm.Dot(radius=.065).at(p).color(WIRE))

    def port(self, net, p, direction='left', label=True):
        x,y=p
        dx,dy={'left':(-.6,0),'right':(.6,0),'up':(0,.6)}[direction]
        end=(x+dx,y+dy)
        self.wire(net,p,end)
        self.ports.append(dict(net=net, p=list(end), kind='label'))
        if label:
            if direction=='up': self.text(end[0],end[1]+.38,net,size=10,color=WIRE,align='center')
            else: self.text(end[0],end[1]+.40,net,size=10,color=WIRE,
                           align='left' if direction=='right' else 'right')

    def ground(self, p):
        self.d.add(elm.Ground().at(p).color(WIRE))
        self.ports.append(dict(net='GND', p=list(p), kind='ground'))

    def nc(self, p):
        self.d.add(elm.NoConnect().at(p).color(AMBER))
        self.ncs.append(list(p))

    def terminal(self, ref, pin, point):
        pin=str(pin)
        assert pin in PARTS[ref]['pins'], (ref,pin)
        key=f'{ref}.{pin}'
        assert key not in DRAWN, f'Duplicate physical terminal {key}'
        info=dict(ref=ref,pin=pin,net=PARTS[ref]['pins'][pin],p=list(point),sheet=self.number)
        self.terminals.append(info); DRAWN[key]=info

    def two(self, ref, a, b, *, pin1='1', pin2='2', kind=None, label=True, side='above', value=None):
        data=PARTS[ref]
        kind=kind or data['kind']
        cls={'R':elm.ResistorIEC,'C':elm.Capacitor,'L':elm.Inductor2,
             'TVS':elm.DiodeTVS,'schottky':elm.Schottky,'switch':elm.Button,
             'crystal':elm.Crystal,'LED':elm.LED}[kind]
        element=cls().at(a).to(b)
        if not data['fitted']: element.color(AMBER)
        self.d.add(element)
        self.terminal(ref,pin1,element.start);self.terminal(ref,pin2,element.end)
        x=(a[0]+b[0])/2; y=(a[1]+b[1])/2
        val=value or data['value']
        if label:
            col=AMBER if not data['fitted'] else INK
            if abs(a[0]-b[0])<1e-6:
                sign=-1 if side=='left' else 1
                self.text(x+sign*.5,y+.3,ref,size=11,color=col,align='right' if sign<0 else 'left')
                self.text(x+sign*.5,y-.35,val,size=9,color=col,align='right' if sign<0 else 'left')
                self.supplier(ref,x+sign*.5,y-.94,align='right' if sign<0 else 'left')
            else:
                sign=-1 if side=='below' else 1
                raised = .45 if kind in ('L','switch') else 0
                self.text(x,y+sign*(1.65+raised),ref,size=11,color=col,align='center')
                self.supplier(ref,x,y+sign*(1.05+raised),align='center')
                self.text(x,y+sign*(.45+raised),val,size=9,color=col,align='center')
        return element

    def cap(self, ref, x, y, length=2.4, side='right'):
        e=self.two(ref,(x,y),(x,y-length),side=side)
        self.ground(e.end)
        return e

    def ic(self, ref, a, b, pins, *, title=None, subtitle=None):
        """pins: (pin number, pin name, side, position along that side)."""
        self.box(a,b,fill='#f5f9f8')
        x1,y1=a; x2,y2=b
        self.text((x1+x2)/2,(y1+y2)/2+.4,title or ref,size=13,align='center')
        self.text((x1+x2)/2,(y1+y2)/2-.45,subtitle or PARTS[ref]['value'],size=9,align='center',color=MUTED)
        self.supplier(ref,(x1+x2)/2,(y1+y2)/2-1.12,align='center')
        anchors={}
        for numbers,name,side,pos in pins:
            nums=str(numbers).split(',')
            if side=='L':
                inside=(x1,pos);end=(x1-.65,pos)
                self.text(x1+.25,pos,name,size=10)
                self.text(x1-.3,pos+.28,str(numbers),size=8,align='right',color=MUTED)
            elif side=='R':
                inside=(x2,pos);end=(x2+.65,pos)
                self.text(x2-.25,pos,name,size=10,align='right')
                self.text(x2+.3,pos+.28,str(numbers),size=8,color=MUTED)
            elif side=='B':
                inside=(pos,y1);end=(pos,y1-.65)
                self.text(pos,y1+.4,name,size=9,align='center')
                self.text(pos+.15,y1-.35,str(numbers),size=8,color=MUTED)
            else:
                inside=(pos,y2);end=(pos,y2+.65)
                self.text(pos,y2-.4,name,size=9,align='center')
                self.text(pos+.15,y2+.35,str(numbers),size=8,color=MUTED)
            # A pin stub is part of the symbol, not an external wire.
            self.rule(inside,end,color=INK,lw=1.2)
            nets={PARTS[ref]['pins'][n] for n in nums}
            assert len(nets)==1, (ref,nums,nets)
            for n in nums: self.terminal(ref,n,end); anchors[n]=end
        return anchors

    def fet(self, ref, drain_or_source):
        cls=elm.PMos if PARTS[ref]['kind']=='PMOS' else elm.NMos
        e=self.d.add(cls(diode=True).at(drain_or_source).theta(0))
        for pin,anchor,name in [('1',e.gate,'G'),('2',e.source,'S'),('3',e.drain,'D')]:
            self.terminal(ref,pin,anchor)
            self.text(anchor.x+(.25 if name!='G' else -.15),anchor.y+.3,f'{pin} {name}',size=8,
                      align='left' if name!='G' else 'right',color=MUTED)
        self.text(drain_or_source[0]+1.2,drain_or_source[1]-1.1,ref,size=11)
        self.text(drain_or_source[0]+1.2,drain_or_source[1]-1.75,PARTS[ref]['value'],size=9)
        self.supplier(ref,drain_or_source[0]+1.2,drain_or_source[1]-2.4)
        return e

    def testpoint(self, ref, p):
        self.d.add(elm.Dot(open=True,radius=.12).at(p).color(INK))
        self.terminal(ref,'1',p)
        self.text(p[0],p[1]+.6,ref,size=10,align='center')
        self.port(PARTS[ref]['pins']['1'],p,'right')
        self.supplier(ref,p[0]-.3,p[1]-.65)

    def finish(self):
        # Add junction dots at physical wire branches and component tees.
        pts={tuple(t['p']) for t in self.terminals if t['net'] is not None}
        pts.update(tuple(w['a']) for w in self.wires)
        pts.update(tuple(w['b']) for w in self.wires)
        for p in pts:
            on=[w for w in self.wires if LineString([w['a'],w['b']]).distance(Point(p))<1e-6]
            degree=sum(1 if p in [tuple(w['a']),tuple(w['b'])] else 2 for w in on)
            degree+=sum(Point(t['p']).distance(Point(p))<1e-6 for t in self.terminals if t['net'] is not None)
            if degree>=3:self.dot(p)
        target=ASSETS/f'{self.number:02d}-{self.slug}.svg'
        self.d.save(target,transparent=False)
        svg=target.read_text()
        svg=svg.replace('<svg ',f'<svg role="img" aria-label="{html.escape(self.title)}" ',1)
        target.write_text(svg)
        self.file=target.name


def sheet_usb():
    s=Sheet(1,'usb-charge','USB-C 输入与电池充电','6Pin 电源接口 · 独立 CC 下拉 · 100 mA 线性充电',[
        'ESD 紧邻接口；线路先经过保护连接点再入板，地端就近落过孔。CC1、CC2 不短接。',
        'C101 紧邻 U100.4，C102 紧邻 U100.3；R105 靠 PROG，回地靠 U100.2，充电区铺地散热。',
        'J101 只接带保护电池包 P+/P−。MSTP4054 不含电芯保护或 NTC；最终电池须允许 100 mA 充电。',
        'CHG_N 低表示充电中；高电平需结合 USB_PRESENT_N 判断。D101～D103 为双向 ESD，不是持续过压保护。'])
    s.section(2,26,'A / USB-C 与输入旁路')
    p=s.ic('J100',(2,19),(8,24.8),[
        ('A9,B9','VBUS','R',23.5),('A5','CC1','R',21.9),('B5','CC2','R',20.3),
        ('A12,B12','GND','B',3.7),('17,18,19,20','SHIELD','B',6.6)],subtitle='HX TYPE-C 6P QTWT')
    for pin,net in [('A9','VBUS_5V'),('A5','USB_CC1'),('B5','USB_CC2')]:
        s.wire(net,p[pin],(10,p[pin][1]));s.port(net,(10,p[pin][1]),'right')
    for pin in ['A12','17']:s.ground(p[pin])
    for ref,x in [('C100',14),('D101',18)]:
        e=s.two(ref,(x,23.5),(x,20.8),value='100nF / 16V' if ref=='C100' else 'ESD, bidir.')
        s.ground(e.end)
    s.wire('VBUS_5V',(14,23.5),(18,23.5));s.port('VBUS_5V',(14,23.5),'up')
    s.section(24,26,'B / 每路 CC 独立下拉与保护')
    for i,x in enumerate([25,37]):
        net=f'USB_CC{i+1}'
        s.port(net,(x,23.5),'up')
        s.wire(net,(x,23.5),(x+4,23.5))
        for ref,xx in [(f'R{100+i}',x),(f'D{102+i}',x+4)]:
            e=s.two(ref,(xx,23.5),(xx,20.8),value='5.1k / 1%' if ref.startswith('R') else 'ESD, bidir.')
            s.ground(e.end)
    s.text(25,18.9,'D101–D103  /  PESDNC2FD5VB',size=10,color=MUTED)
    s.section(2,17,'C / 充电器与带保护软包电池')
    p=s.ic('U100',(10,9.1),(18,15.6),[
        ('4','VCC','L',14.3),('5','PROG','L',11.3),('2','GND','B',14),
        ('3','BAT','R',14.3),('1','CHRG','R',11.3)])
    s.wire('VBUS_5V',p['4'],(6,14.3));s.port('VBUS_5V',(6,14.3),'up')
    s.cap('C101',6,14.3,side='left')
    s.wire('CHG_PROG',p['5'],(8,11.3),(8,10.8))
    e=s.two('R105',(8,10.8),(8,8.3),side='left');s.ground(e.end)
    s.ground(p['2'])
    s.wire('VBAT',p['3'],(23,14.3),(29,14.3));s.port('VBAT',(29,14.3),'right')
    s.cap('C102',23,14.3)
    s.wire('CHG_N',p['1'],(20.5,11.3),(20.5,8.6));s.port('CHG_N',(20.5,8.6),'right')
    s.text(10,7.5,'RPROG = 10k → ICHG ≈ 100mA',size=10,color=MUTED)
    s.port('VDD',(28,11.5),'up')
    e=s.two('R106',(28,11.5),(28,8.5))
    s.wire('CHG_N',e.end,(31.5,8.5));s.port('CHG_N',(31.5,8.5),'right')
    p=s.ic('J101',(35,11.5),(39.7,15.5),[('1','P+','L',14.5),('2','P−','L',12.5)],subtitle='焊线焊盘')
    s.port('VBAT',p['1'],'left');s.ground(p['2'])
    e=s.d.add(elm.BatteryCell().at((43,14.5)).to((43,11.7)))
    # BatteryCell.start is the positive (long-line) terminal.
    s.terminal('BAT1','+',e.start);s.terminal('BAT1','-',e.end)
    s.port('VBAT',e.start,'up');s.ground(e.end)
    s.text(43,10.5,'1S / 4.2V',size=10,align='center')
    s.text(43,9.7,'带保护 / ~320mAh',size=9,align='center')
    s.supplier('BAT1',43,8.9,align='center')
    return s


def sheet_power():
    s=Sheet(2,'power-sense','供电切换、稳压与检测','USB / 电池自动切换 · 3.3 V MCU / RGB 电源 · 低有效 USB 检测',[
        'Q100：1=G、2=S→VSYS、3=D→VBAT；体二极管为 VBAT→VSYS。D100：2=A→VBUS、1=K→VSYS。',
        'D100、Q100、C103 与 LDO 靠近；C103 靠 VIN，C104 靠 VOUT/GND。充电支路与系统支路在电池入口分开。',
        'R110/R111/C105 靠 ADC，避开 RF、DCC、PWM；SAADC 内部参考 0.6V、增益 1/6、采集 40µs，上电等 ≥250ms。',
        'R104 测量 VDD 支路电流，包含 MCU 与 RGB；不隔离整机。电池低压时 VDD 会低于 3.3V。'])
    s.section(2,26,'A / USB 与电池通路')
    s.port('VBUS_5V',(4.5,24),'left')
    s.wire('VBUS_5V',(4.5,24),(6,24))
    e=s.two('D100',(6,24),(9,24),pin1='2',pin2='1',value='BAT54H')
    s.text(6,23.55,'2 A',size=8,color=MUTED);s.text(9,23.55,'1 K',size=8,color=MUTED,align='right')
    q=s.fet('Q100',(21,22.8))
    s.wire('VSYS',e.end,(21,24),q.source);s.port('VSYS',(21,24),'up')
    s.wire('VBAT',q.drain,(21,18.7),(22,18.7));s.port('VBAT',(22,18.7),'right')
    gy=q.gate.y
    s.port('VBUS_5V',(10.5,gy),'left');s.wire('VBUS_5V',(10.5,gy),(12,gy))
    e=s.two('R102',(12,gy),(15,gy),label=False)
    # Keep the ref below the VSYS wire; place the supplier ID below the resistor.
    s.text(13.5,gy+1.05,'R102',size=11,align='center')
    s.text(13.5,gy+.45,PARTS['R102']['value'],size=9,align='center')
    s.supplier('R102',13.5,gy-.75,align='center')
    s.wire('BAT_PATH_GATE',e.end,q.gate)
    s.wire('BAT_PATH_GATE',(17.6,gy),(17.6,gy-.6))
    e=s.two('R103',(17.6,gy-.6),(17.6,18.1),side='left');s.ground(e.end)
    s.text(3,18.4,'插线：Q100 关闭 / D100 供电',size=10,color=MUTED)
    s.section(27,26,'B / 3.3 V 稳压')
    p=s.ic('U101',(30,18.8),(36,24.7),[('1','VIN','L',23.2),('3','CE','L',21),
        ('2','VSS','B',33),('5','VOUT','R',23.2),('4','NC','R',21)],subtitle='ME6211C33M5G-N')
    s.wire('VSYS',p['1'],(28,23.2),(27,23.2));s.port('VSYS',(27,23.2),'up')
    s.wire('VSYS',p['3'],(28,21),(28,23.2));s.cap('C103',27,23.2,3.5,side='left')
    s.ground(p['2']);s.nc(p['4'])
    s.wire('VREG_3V3',p['5'],(38.5,23.2),(40,23.2));s.cap('C104',38.5,23.2,3.5)
    e=s.two('R104',(40,23.2),(43,23.2));s.wire('VDD',e.end,(44.5,23.2));s.port('VDD',(44.5,23.2),'right')
    s.text(40,18.9,'VREG_3V3 → R104 → VDD',size=9,color=MUTED,align='center')
    s.section(2,16.6,'C / USB 检测（GPIO 无 5V 直连）')
    q=s.fet('Q101',(12,12.5));s.ground(q.source)
    e=s.two('R109',(12,15.7),q.drain);s.port('VDD',e.start,'up')
    s.wire('USB_PRESENT_N',q.drain,(17,12.5));s.port('USB_PRESENT_N',(17,12.5),'right')
    gy=q.gate.y
    s.port('VBUS_5V',(4,gy),'left');s.wire('VBUS_5V',(4,gy),(5,gy))
    e=s.two('R107',(5,gy),(8,gy));s.wire('USB_GATE',e.end,q.gate)
    e=s.two('R108',(9.2,gy),(9.2,7.6),side='left');s.ground(e.end)
    s.text(15,8.1,'有 USB → USB_PRESENT_N = 0',size=9,color=MUTED)
    s.section(27,16.6,'D / 电池电压 / 2')
    e=s.two('R110',(29,15),(29,12));s.port('VBAT',e.start,'up')
    e=s.two('R111',(29,12),(29,8.7));s.ground(e.end)
    s.wire('VBAT_SENSE',(29,12),(35,12),(41,12));s.port('VBAT_SENSE',(41,12),'right')
    s.cap('C105',35,12,3.3)
    s.text(38,9,'U200.4 / P0.02 / AIN0',size=10,color=MUTED)
    return s


def sheet_mcu_power():
    s=Sheet(3,'mcu-power','nRF52832 电源与内部 DC/DC','U200 的电源分单元 · QFAA / QFN48 · DEC 网络独立',[
        'C200/C201/C202 紧贴对应 DEC 引脚；就近接地，三个 DEC 不互连，不用于外部供电。DEC2 / pin 32 不接。',
        'C203 靠 pin 13；C204 靠 pin 36；C205/C206 靠 pin 48。EP 必须连接完整地平面并设置接地过孔。',
        'DCC → 10µH → 15nH → DEC4，紧凑布局；DCC 节点避开晶体/RF。L200 采用 MLZ1608M100WT000（≥50mA）。',
        '默认装 L200/L201，固件开启 DC/DC；内部 LDO 调试时两电感 DNP、DCC 悬空、C202 保留。核对 C202/C205 的替代规格。'])
    p=s.ic('U200',(17,9.1),(27,25.6),[
        ('13','VDD','L',23.5),('36','VDD','L',19.5),('48','VDD','L',15.5),
        ('32','DEC2','L',12),('44','NC','L',10.5),
        ('1','DEC1','R',23.5),('33','DEC3','R',19.5),('46','DEC4','R',15.5),('47','DCC','R',11),
        ('31','VSS','B',19),('45','VSS','B',22),('EP','EP','B',25)],title='U200 · POWER',subtitle='nRF52832-QFAA / 6 × 6 mm')
    for pin,ref,y in [('13','C203',23.5),('36','C204',19.5)]:
        s.wire('VDD',p[pin],(10,y),(6,y));s.port('VDD',(6,y),'up');s.cap(ref,10,y,2.5)
    s.wire('VDD',p['48'],(10,15.5),(5,15.5));s.port('VDD',(5,15.5),'up')
    s.cap('C205',5,15.5,2.5);s.cap('C206',10,15.5,2.5)
    for pin in ['32','44']:s.nc(p[pin])
    for pin in ['31','45','EP']:s.ground(p[pin])
    for pin,ref,y in [('1','C200',23.5),('33','C201',19.5),('46','C202',15.5)]:
        net=PARTS['U200']['pins'][pin]
        s.wire(net,p[pin],(34,y));s.cap(ref,34,y,2.6)
        s.text(29,y+.45,net,size=10,color=WIRE)
    s.wire('DCC',p['47'],(29,11),(29,9.8),(30,9.8))
    e=s.two('L200',(30,9.8),(34,9.8))
    s.wire('DCDC_MID',e.end,(35.5,9.8))
    e=s.two('L201',(35.5,9.8),(39.5,9.8))
    s.wire('DEC4',e.end,(43,9.8),(43,15.5),(34,15.5))
    s.text(39.5,22.5,'DEC1 ≠ DEC3 ≠ DEC4',size=11,color=WIRE,align='center')
    s.text(39.5,21.3,'内部稳压节点',size=10,color=MUTED,align='center')
    s.text(39.5,20.4,'禁止与 VDD 短接',size=10,color=MUTED,align='center')
    return s


def sheet_clock_rf():
    s=Sheet(4,'clock-rf','时钟与 2.4 GHz 射频','两组晶体负载 · Nordic 芯片端参考网络 · 陶瓷天线匹配预留',[
        '晶体及负载电容紧贴对应 MCU 脚、短线/少过孔；下方不走 DCC/PWM/SWD。X200 的 2/4 为外壳接地。',
        '按已有开发板用值：HF、LF 每侧各一颗 12pF 到地，共 C210–C213 四颗；电容靠对应晶体端放置。',
        'C216 在 ANT 引脚一侧，地端紧靠 U200.31/EP；C216/L220 局部布局复制 Nordic。RF_50 以后按实际叠层定 50Ω。',
        'C217/C218 首版 DNP；装壳后调匹配。ANT200.2 为 NC；按厂家净空图放置，远离电池铝膜、USB 壳和金属件。'])
    s.section(2,26,'A / 32 MHz  ·  CL = 10 pF  ·  每侧 1 × 12 pF')
    e=s.two('X200',(9,23),(15,23),pin1='1',pin2='3',kind='crystal',value='32MHz / YE32MDBCD2X')
    s.text(9,22.55,'1',size=8,color=MUTED);s.text(15,22.55,'3',size=8,color=MUTED)
    s.wire('XC1',e.start,(5,23));s.port('XC1',(5,23),'up')
    s.wire('XC2',e.end,(19,23));s.port('XC2',(19,23),'up')
    for ref,x in [('C210',5),('C211',19)]:
        s.cap(ref,x,23,2.5,side='left' if x==19 else 'right')
    # The crystal's two case pads are separate from the resonant terminals.
    s.box((10.6,21.4),(13.4,23.8),color=RULE,ls='--',lw=.8)
    for pin,x in [('2',11.3),('4',12.7)]:
        s.rule((x,21.4),(x,20.5),color=INK)
        s.terminal('X200',pin,(x,20.5));s.ground((x,20.5))
        s.text(x,21, pin,size=8,color=MUTED)
    s.section(26,26,'B / 32.768 kHz  ·  CL = 12.5 pF  ·  每侧 1 × 12 pF')
    e=s.two('X201',(33,23),(39,23),kind='crystal',value='32.768kHz / KFC3276812520T')
    s.text(33,22.55,'1',size=8,color=MUTED);s.text(39,22.55,'2',size=8,color=MUTED)
    s.wire('XL1',e.start,(29,23));s.port('XL1',(29,23),'up')
    s.wire('XL2',e.end,(43,23));s.port('XL2',(43,23),'up')
    for ref,x in [('C212',29),('C213',43)]:
        s.cap(ref,x,23,2.5,side='left' if x==43 else 'right')
    s.section(2,18.5,'C / 主控时钟与 RF 单元')
    p=s.ic('U200',(5,8.8),(13,17.1),[
        ('34','XC1','L',15.7),('35','XC2','L',14.1),('2','P0.00 / XL1','L',12.5),('3','P0.01 / XL2','L',10.9),
        ('30','ANT','R',14.1)],title='U200 · RF / CLK',subtitle='nRF52832-QFAA')
    for pin in ['34','35','2','3']:s.port(PARTS['U200']['pins'][pin],p[pin],'left')
    s.wire('RF_ANT',p['30'],(16,14.1),(18,14.1));s.cap('C216',16,14.1,2.8)
    e=s.two('L220',(18,14.1),(23,14.1))
    s.wire('RF_50',e.end,(26,14.1),(29,14.1));s.cap('C217',26,14.1,2.8)
    e=s.two('R221',(29,14.1),(33,14.1))
    s.wire('ANT_FEED',e.end,(35,14.1),(39.35,14.1));s.cap('C218',35,14.1,2.8)
    p=s.ic('ANT200',(40,12.4),(46,16.4),[('1','INPUT','L',14.1),('2','NC','B',44)],subtitle='KH-2012-HM1')
    s.nc(p['2'])
    s.text(16,16.4,'Nordic QFN48 参考初值',size=10,color=WIRE)
    s.text(26,16.4,'天线 π 匹配预留',size=10,color=AMBER)
    s.text(24,13.5,'RF_50',size=9,color=WIRE)
    s.text(34,13.5,'ANT_FEED',size=9,color=WIRE)
    s.text(16,9.2,'ANT 侧 → C216 → L220 这一段不按普通 50Ω 长线处理',size=10,color=MUTED)
    return s
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

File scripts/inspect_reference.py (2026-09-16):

from pathlib import Path
import zipfile,xml.etree.ElementTree as E
import trimesh,numpy as np
import matplotlib
matplotlib.use('Agg')
import matplotlib.pyplot as plt
NS={'m':'http://schemas.microsoft.com/3dmanufacturing/core/2015/02'}
def meshes(name):
 with zipfile.ZipFile(Path('reference/enclosure')/(name+'.3mf')) as z:r=E.fromstring(z.read('3D/3dmodel.model'))
 out={}
 for o in r.findall('.//m:object',NS):
  v=np.array([[float(e.get(a)) for a in ('x','y','z')] for e in o.findall('.//m:vertex',NS)])
  f=np.array([[int(e.get(a)) for a in ('v1','v2','v3')] for e in o.findall('.//m:triangle',NS)])
  v=np.column_stack((-v[:,0],v[:,2],v[:,1]))
  out[o.get('name')]=trimesh.Trimesh(v,f,process=True)
 return out
if __name__=='__main__':
 fig,axs=plt.subplots(2,5,figsize=(18,10))
 for row,name in enumerate(('shell_top','shell_bottom')):
  m=list(meshes(name).values())[0]
  print(name,m.bounds,m.is_watertight,m.volume)
  for ax,z in zip(axs[row],[-1,-2.4,-5,-8,-12]):
   s=m.section(plane_origin=[0,0,z],plane_normal=[0,0,1])
   if s:
    for p in s.discrete:ax.plot(p[:,0],p[:,1],lw=.7)
   ax.set_aspect('equal');ax.set_title(name+' z='+str(z));ax.set_xlim(-23,23);ax.set_ylim(-72,72);ax.grid()
 fig.tight_layout();fig.savefig('output/review/reference-sections.png',dpi=150)
 for name,m in meshes('buttons_blank').items():print(name,m.bounds.tolist(),m.is_watertight)

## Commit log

2026-09-16 Publish remote mechanical models and GitHub Pages preview
    [The Everything Remote - The Stock Pot_BOM_PCBWay_PCBWay Community.xlsx, battery.stl, buttons_blank.3mf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]
2026-09-16 Use JLC 6-pin USB model and initialize uv
    [C18357553.obj, C318938.obj, C52212029.obj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]
2026-09-17 Publish electrical schematic and BOM as standalone pages
2026-09-17 Draw reviewed schematics with Schemdraw and publish interactive viewer
2026-09-19 Annotate schematic components with JLC part numbers
2026-09-20 Use one 12pF load per crystal terminal and renumber capacitors
2026-09-20 Connect button contacts directly to GPIO and remove RC filters
2026-09-20 Drive RGB LED directly from GPIO on VDD
2026-09-22 Update enclosure for bottom USB and microphone port
    [printable_parts.3mf, remote_assembly.3mf, shell_bottom.stl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]
2026-09-22 Correct bottom USB orientation and end latch geometry
    [pcb.stl, pcb_outline.dxf, printable_parts.3mf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]
2026-09-23 Sync final PCB mounting hole and bottom USB registration
    [pcb.stl, pcb_outline.dxf, printable_parts.3mf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]
2026-09-23 Add preliminary openEMS antenna study and published RF report
    [eps40.csv, housed.csv, nominal.csv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]
2026-09-24 Use confirmed 1.6 mm PCB thickness for enclosure and USB fit
    [pcb.stl, printable_parts.3mf, remote_assembly.3mf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]
2026-09-24 Recalculate preliminary antenna match for confirmed 1.6 mm board
    [housed-16.csv, nominal-16.csv]
2026-09-28 Recalculate antenna study from final Gerber and JLCPCB material data
    [gerber-bare.csv, gerber-dk43.csv, gerber-fine.csv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]
2026-09-28 Add laminate-specific antenna matching report
    [hy8101-bare.csv, hy8101-housed.csv, np140f-bare.csv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]
